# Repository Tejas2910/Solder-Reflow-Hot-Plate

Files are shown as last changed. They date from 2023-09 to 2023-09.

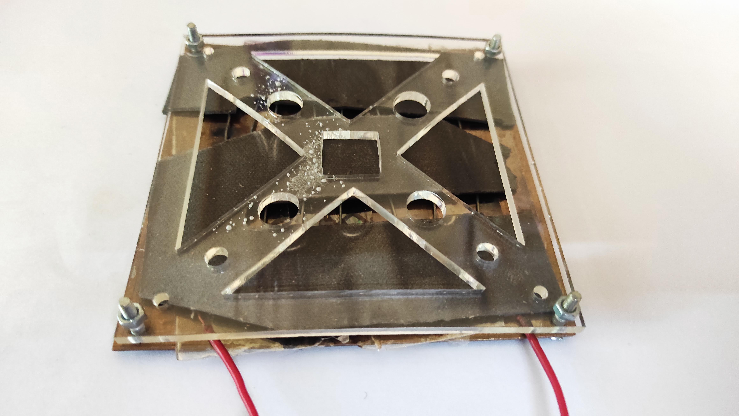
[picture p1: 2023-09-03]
Assembly.jpg

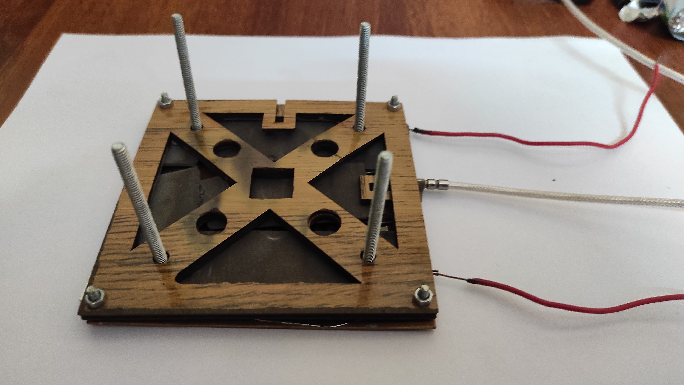
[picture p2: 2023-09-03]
Assembly_Final.jpg

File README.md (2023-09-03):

# Solder-Reflow-Hot-Plate
## Course Project EE344: Electronic Design Lab

Project Details:
 -  Recipient of Best Project Award in the Electrical Engineering Department among 200+ students for creating Solder Reflow Hot Plate instrument to solder SMD components 
 -  Engineered a high-performance heating element reaching temperatures up to 300°C, a cooling mechanism capable
    of dropping temperatures at a maximum rate of 3°C/s, and a precision feedback circuit for temperature control
 -  Collaborated within a 3-member team to design an intuitive web interface for configuring reflow profiles, a user-
    friendly TFT LCD display for real-time information, a 3D-printed enclosure and PCB layouts using Eagle

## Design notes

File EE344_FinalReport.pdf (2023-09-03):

EE344: Electronic Design Lab | Final Project Report

# EE344: Electronics Design Lab

# Final Project Report

# Reflow Oven for Soldering SMD Components

# TUE- 11

Akshata Koshti | 200070034
Darshan Sinnarkar | 20D070079
Tejas Amritkar | 20D070081

### 1. Project Title:

Reflow Oven for Soldering SMD Components

### 2. Group Number: TUES-11

### 3. Team members:

Akshata Koshti 200070034
Darshan Sinnarkar 20D070079 Tejas Amritkar 20D070081
4. Circuit Schematic and Layout: Circuit_Schematic_Layout (https://drive.google.com/drive/folders/1hkzOSJ5yrxFGMIBhelCKWo8H-GT9ofpd?usp=sharing) Also added at the end of the document.

### 5. Project abstract:

Soldering SMD components requires practice, it is time consuming
and the quality of soldering depends on the skill.
Aim of this project is to build a reflow oven which follows a configurable reflow profile accurately and covers a large temperature range. We aim to build the system using Nichrome coil mounted on an Copper plate as heating element, a web-interface to add/configure reflow profile, a simple user interface including screen and buttons and an elegant 3D printed PLA enclosure. Proposed system can also be used for de-soldering SMD components.

### 6. Project Goal:

Goal of the project is build a reflow oven with heating plate size as 100mm x 100mm which covers a large temperature range (up to 300 oC). Reflow oven should have an option to change reflow profile according the solder paste used. The heating plate should be able to drop temperature after reflow profile peak quickly (about 3oC/second). The heating of surface should be approximately even. Reflow oven should have a screen where relevant data (like current temperature) is displayed and a few buttons to control the oven. Entire project is to be enclosed in a suitable enclosure.

### 7. Components:

a. Copper plate:
Copper Plate of dimensions 100x100x2mm is used as heating surface. Copper is chosen because of high conductivity, it is easily available, requires less energy to heat up than aluminium (for same dimensions), dissipates relatively less energy compared to aluminium.

b. Nichrome Coil:
Nichrome wire will be used as a heating element. Resistance of nichrome wire almost remains constant with temperature. Therefore, steady state temperature is entirely dependent on current through the wire.
T directly proportional to I^2 RMS or V^2 RMS.
Ref - http://www.brysonics.com/heating-a-nichrome-wire-with-math/
c. Pt100 temperature sensor:
IT can measure temperature from -200 to 420-

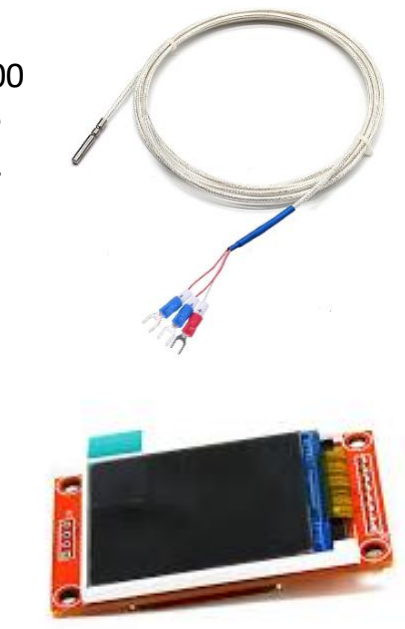
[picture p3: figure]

degree C. At 0°C, the sensor has a resistance of 100
Ohm and resistance increases as the temperature increases. The sensor has a response time of 1ms. The sensor has an accuracy of around 0.385 Ohm/°C.
d. TFT screen
We will use the 1.8 inch TFT LCD to display the current temperature, time and other important parameters on the screen. 1.8 Inch TFT LCD Module display uses 4-wire SPI to communicate and has its own pixel-addressable frame buffer, it can be used with every kind of microcontroller. We can use it with 3.3V(in our case) or 5V power and logic.

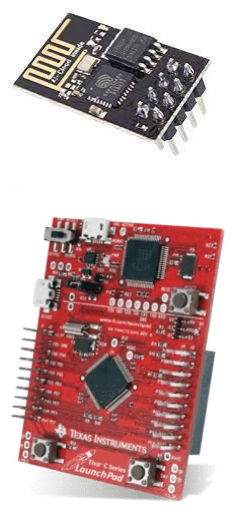
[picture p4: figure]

e. ESP01
The ESP01 is a small, low-cost, and easy-to-use microcontroller board that includes built-in WiFi connectivity. We will be using this microcontroller to host a website and control the reflow oven remotely.
f. TM4C123GH6PM TIva C board

We will be using TM4C123GH6PM Tiva C board as a microcontroller. The board includes a range of peripherals, including UART, I2C, SPI, PWM, 12-bit ADC. The board meets all the feature needed for the
project. It | will be coded with C programming
language.

g. Cooling Fan:
We will be using an 8025 5V cooling fan for cooling mechanism of reflow oven. We are using 80 x 80 x 25 mm casing Frame size of fan which fit comfortably inside the oven.

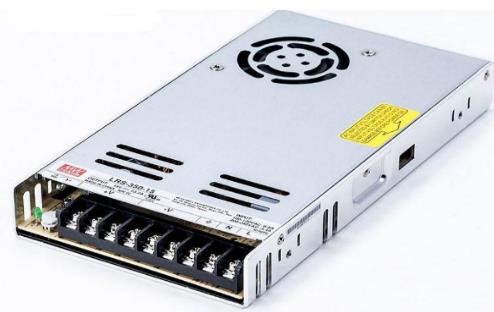
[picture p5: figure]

h. Power supply
We have used SMPS, 12V 10A for supplying power. It provides enough current current to drive our circuit.
i. LM2596
We wil be using LM7805 linear voltage regulator to convert 12 V (from 12 V
adapter) | to 5V DC.
j. Push Button:

We will be using push button to near LCD mounted on the casing. We will use 4 push button to these 4 features: mode select, resume, pause and reset.

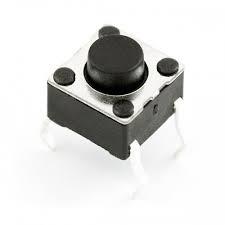
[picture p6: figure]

k. Mica sheet
Mica sheet was easily available and suitable for insulating the copper plate and nichrome coil.
l. Relay
Instead of using IRF3205 power mosfet and 2N2222 for controlling the nichrome coil, relay and related circuits are used which include BC547 NPN BJT and diode 1n4001 (both available in WEL). The circuit diagram is attached. A similar circuit is used for controlling cooling fan.

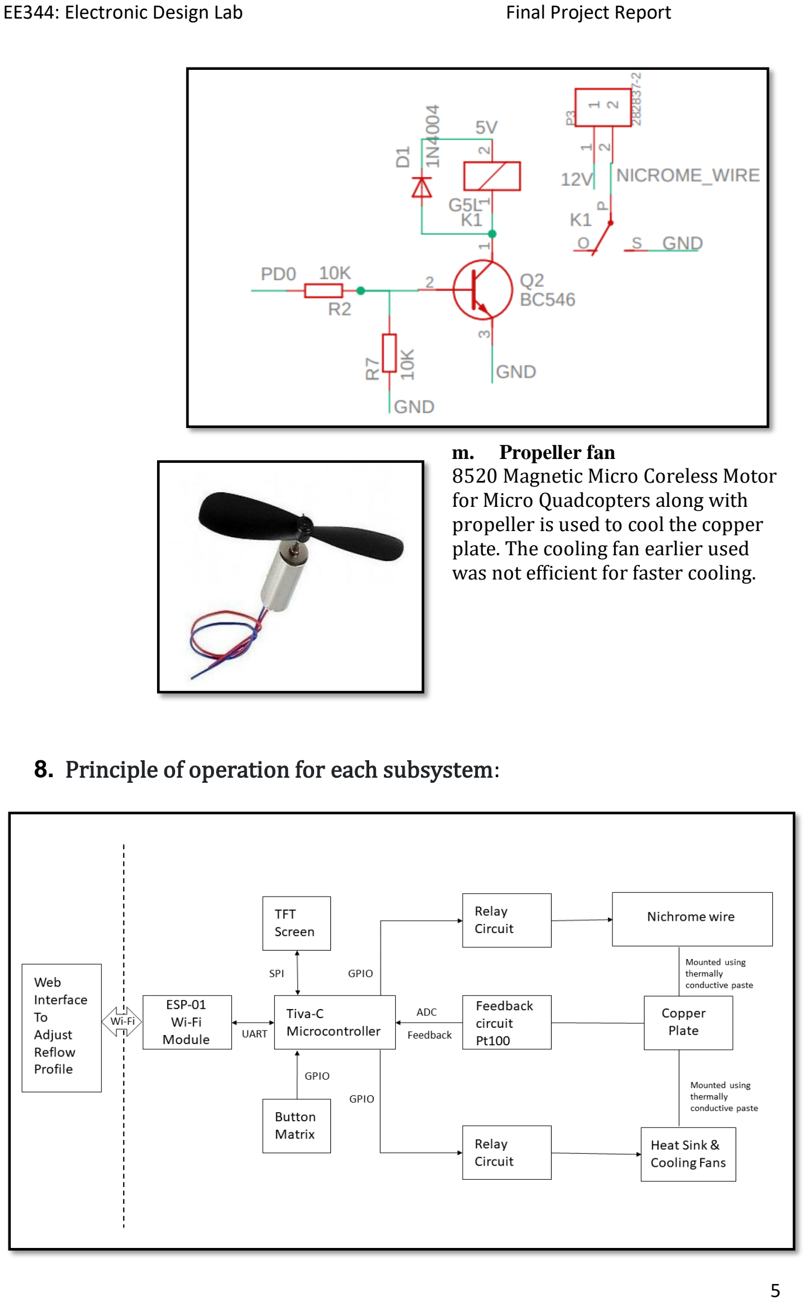
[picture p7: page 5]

m. Propeller fan
8520 Magnetic Micro Coreless Motor for Micro Quadcopters along with propeller is used to cool the copper plate. The cooling fan earlier used was not efficient for faster cooling.

### 8. Principle of operation for each subsystem:

Project consists of following sub-systems:
a. Heating Circuit
b. Cooling Circuit
c. Feedback Circuit
d. Web interface
e. User Interface
a. Heating Circuit:
- Copper Plate of dimensions 100x100x2mm is used as heating surface.
- Nichrome wire will be used as heating element to heat up to desired temperature. It will be power up by the 12 V DC supply.
- Relay circuit is to be used to control power to Nichrome wire using GPIO of microcontroller.
b. Cooling Circuit:
Air Cooling: In order to have an efficient cooling effect 8520 motor is used as cooling fan to transfer heat out of enclosure.
c. Feedback Circuit:
Pt100 temperature sensor along with voltage divider circuit is used as feedback.
d. Web-interface:
We aim to build a web-interface for configuration of reflow profile and to update collected data to user desktop/laptop. To achieve this ESP01 Micro -controller is used.
e. User Interface:
- 1.8’ ST7735 TFT Screen: Screen communicates to Micro-controller using SPI communication and provides user with useful data.
- Button Matrix: Used to take inputs from user to select reflow profile, start/stop process, and other basic utilities.

### 9. Method - Heating element setup:

Copper plate is being used as heating surface. For heating element 22 AWG Nichrome wire (not insulated) is used. There is need to add an electrically insulating layer between copper plate and nichrome wire. For electrical insulation Mica sheet is used between Nichrome wire and copper plate.

For maximum efficiency, full length of Nichrome wire needs to be in strong contact with Mica sheets. Hence entire assembly is as follows:
a. Copper Plate
b. Mica Sheet
c. Nichrome Wire
d. Asbestos sheet for thermal insulation/buffer
e. Two Wooden plates

In absence of Asbestos sheet wooden plate is burnt by heat from
nichrome wire which leads to smoke and burning smell.
A small slit is made in top wooden sheet to hold PT100(Temperature Sensor) in contact with copper plate.
Four Screw-nuts hold the entire assembly together.

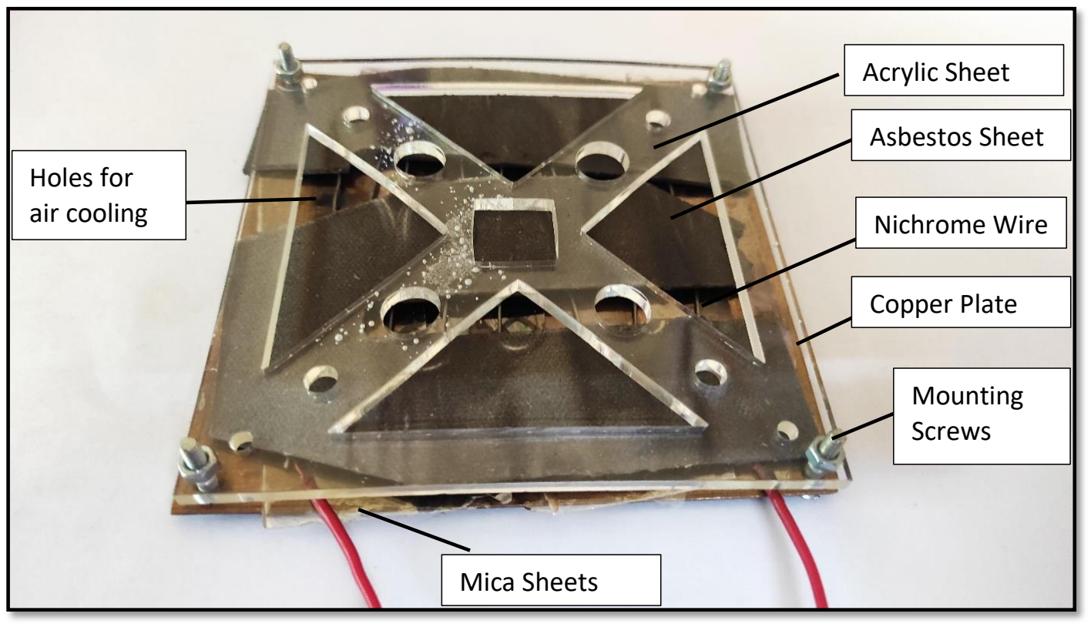
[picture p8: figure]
Acrylic Sheet; Asbestos Sheet; Nichrome Wire; Copper Plate; Mounting Screws; Mica Sheets; Holes for air cooling

First Version of assembly. All layers as described can be clearly seen.

3mm Acrylic sheet was earlier used as last layer, considering temperature on other side of asbestos sheet does not exceed above 150oC, which is below melting point of acrylic(160oC). However, at much lower temperatures Acrylic sheet begins to lose structural integrity and starts deforming.

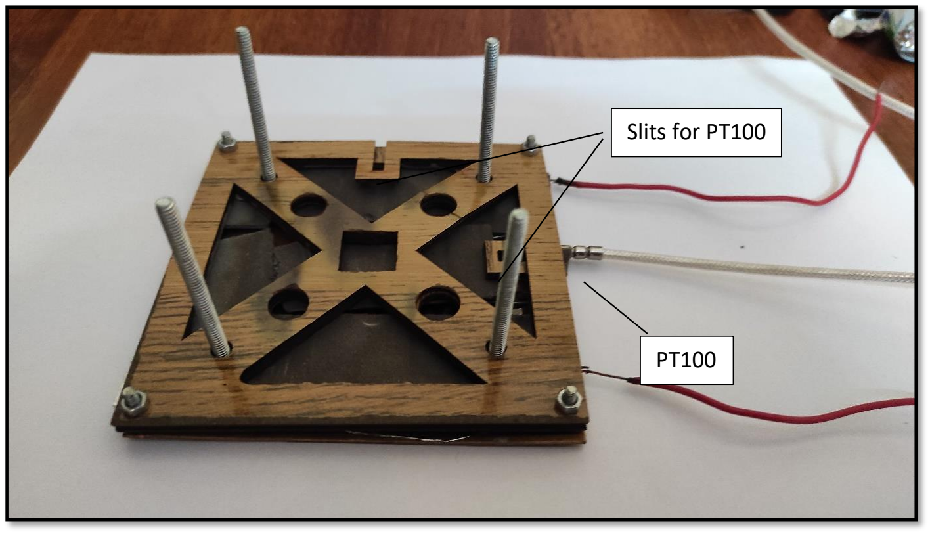
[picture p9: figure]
Slits for PT100

Final Assembly with wooden plates

Long Screws are used to attach this heating subsystem to 3D printed PLA enclosure. These also create a temperature gradient such that PLA does not melt where screws are attached.

Technical Specifications of parts:

1mm thick Copper Plate – 105x105 mm. 22 AWG Nichrome wire with 3Ω resistance. 2mm Asbestos sheet.
Two 2mm 105x105mm wood sheets.
5mm Screws to create temperature gradient.

### 10. Method - ESP-01 Wi-Fi Module Setup:

Wi-Fi Module procured from WEL is ESP-01 module with ESP8266EX micro-controller. It comes with pre-loaded firmware which accepts AT commands through UART.

To create wireless interface to add custom reflow profiles and load in Tiva-C micro-controller.
To achieve this, create a web-server on ESP-01 and host a local website through which user can set custom user profile.

To use this module, it can be interfaced with Tiva-C using UART and AT commands can be used to interact with Wi-Fi module. However, this is inefficient architecture as it creates additional load on Tiva-C micro-controller, takes up storage space of Tiva-C and large amount of data is transferred over UART.

Instead, we can use ESP-01 on-board flash to store program and use computing capabilities of ESP8266EX MCU to share computing load on Tiva-C.

Steps:

1. Download and set-up ESP8266 RTOS SDK with Msys32 from Espressif website. (Documentation) (https://docs.espressif.com/projects/esp8266-rtos-sdk/en/latest/get-started/)
2. Run mingw32.exe and run these commands before every use. PATH="${HOME}/xtensa-lx106-elf/bin:${PATH}"
export IDF_PATH=~/esp/ESP8266_RTOS_SDK
3. Use template code from
(SDK_PATH)/examples/protocols/http_server/simple
and modify it according to needs.
4. Create suitable webpage HTML and JavaScript files and add them as EMBED files. For this, save html and JavaScript files in main directory and add following lines in CMakeLists.txt and component.mk.

CMakeLists.txt =>

component.mk =>

5. Referring to example provided create suitable URI and use HTTP GET to get data from browser.
6. Use a USB-UART converter and use the following schematic.

PATH="${HOME}/xtensa-lx106-elf/bin:${PATH}" export IDF_PATH=~/esp/ESP8266_RTOS_SDK

register_component(EMBED_FILES upoad_script.html")

COMPONENT_EMBED_FILES += upload_script.html

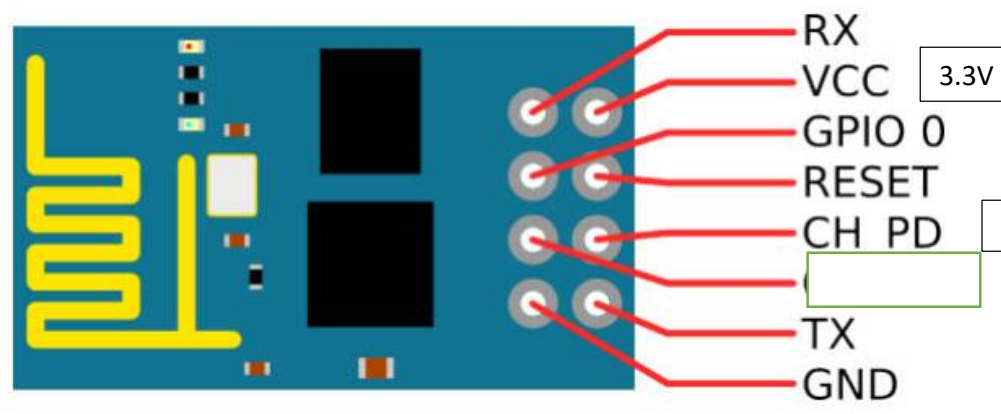
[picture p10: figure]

7. Use menuconfig to set upload port as mentioned in documentation in Step 1 and flash custom firmware.
8. While flashing connect GND to GPIO 0 to put the module in boot mode. Later connect RESET pin to GND for a second and release to activate the normal configuration.
9. Connect the ESP-01 module to Tiva-C through UART and read data as collected through web-interface.

Before executing Step 6, check the flash usage. We have upgraded the default flash of 1 MB in ESP-01 to 4 MB.

3.3V

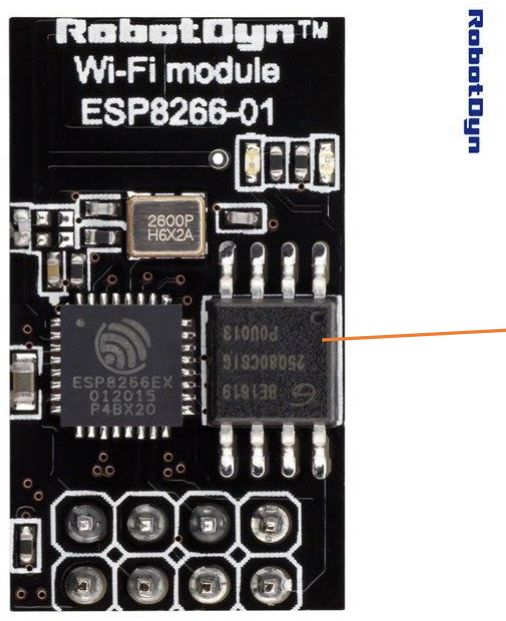
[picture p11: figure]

Upgrade this flash to 4 MB to store html and JavaScript
files.
(Plotly JavaScript Library as described later can also be stored in the flash)

### 11. Method - Feedback circuit:

Pt100 RTD temperature sensor is used to take temperature reading of the hot copper plate. Pt100 changes its resistance values nearly in linear proportion with the temperature. Temperature reading is used to switch on/off relay circuit which further switched on/off current going through nichrome coil and fan.

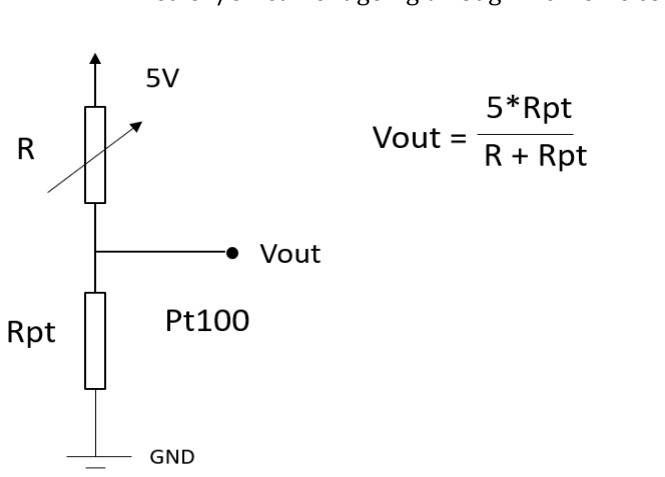
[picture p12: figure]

Pt100 temperature sensor is put in a voltage divider circuit with another resistor Rs as shown in the figure. We have used potentiometer in instead of constant Rs, with a value of 120 Ohm. Output of this circuit (Vout) is an input to Micro-controller through an in-built 12-bit Analog-to-Digital converter (ADC). Resistance of the Pt100 is calculated from the Vout with the formula shown in figure. We found that temperature of the Pt100 varies linearly with its resistance value as shown:

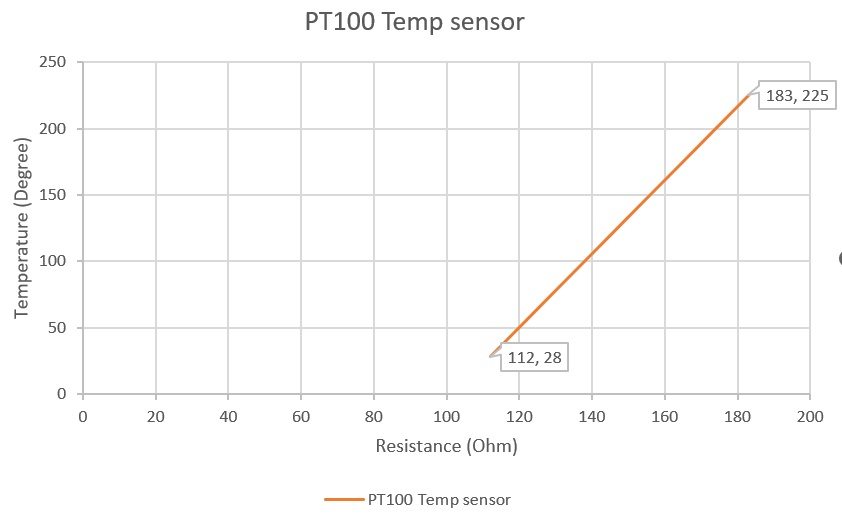
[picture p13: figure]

(Note: Feedback circuit in the prototype is not on PCB because the routes had lot of noise as it was incorrectly placed near 6A routes.)

### 12. Method - Cooling Circuit:

8520 Magnetic Micro Coreless Motor for Micro Quadcopters along with propeller is used as a cooling mechanism. Both nichrome coil and fan is controlled with relay circuit. If the temperature is below 220 degree C, we keep the fan switched off and nichrome coil is switched on. If the temperature is between 220-2330 degree C, we start the cooling fan with nichrome coil switched on. If the temperature is above 2330 degree C, fan is switched on and nichrome coil is switched off.

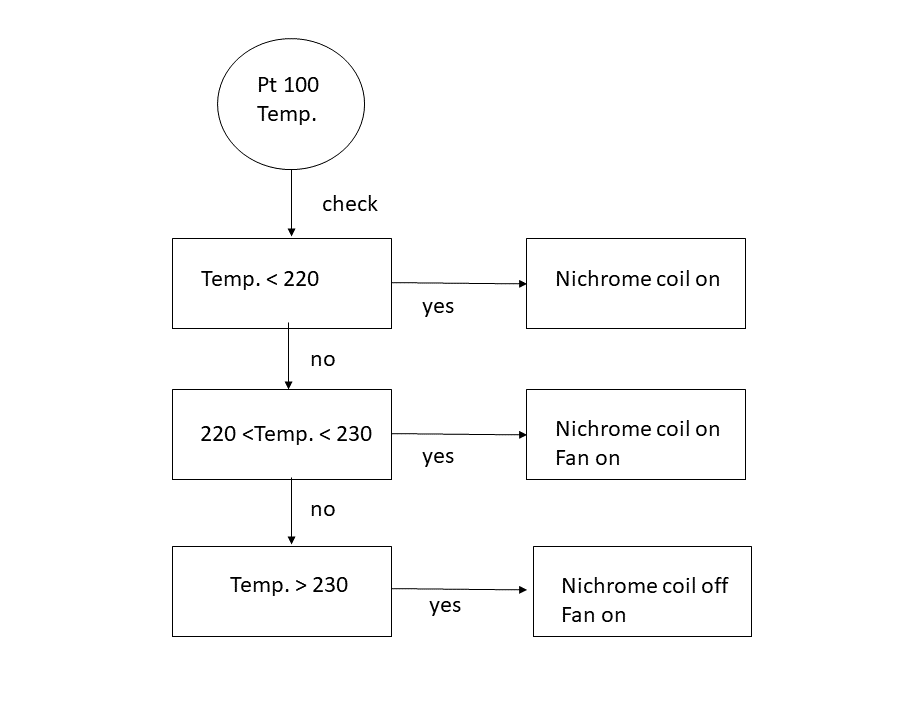
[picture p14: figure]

### 13. Method - User Interface

1.8’ ST7735 TFT Screen is used to show useful data such as current temperature, time elapsed, resistance value of pt100, current status of nichrome coil, percentage of completion of reflow process. TFT screen communicates to micro-controller using SPI communication.

Test setup and method:

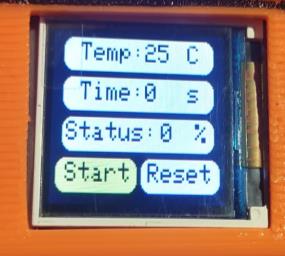
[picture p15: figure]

1. TFT screen is interfaced using SPI communication as shown.
- MOSI(Master Output Slave Input): (PIN SDA) Used by Tiva C to send the data TFT screen.
- SCK(Serial Clock): (PIN SCK) Used to synchronous the transfer of data between the Tiva C and screen. The clock is generated by the Tiva C.
- SS(Slave select): (PIN CS) Used to select the slave device with which Tiva C wants to communicate.
- RESET: Used to reset the TFT screen.
- LED: This is the backlight pin, which is used to control the brightness of the screen backlight.
- A0(D/C): This is the data/command pin, which is used to differentiate between data and command signals.

14.Method - Integrated Setup:

In this part, we integrated all subsystems.

Tiva-C MCU was programmed accordingly and it was controlling the temperature of Copper plate while displaying technical details on screen.

a. Heating element:

Connected using relay circuit as mentioned. Circuit was designed using NPN transistor (BC547), diode(1N4001) and a (5V, 5 pin) relay.

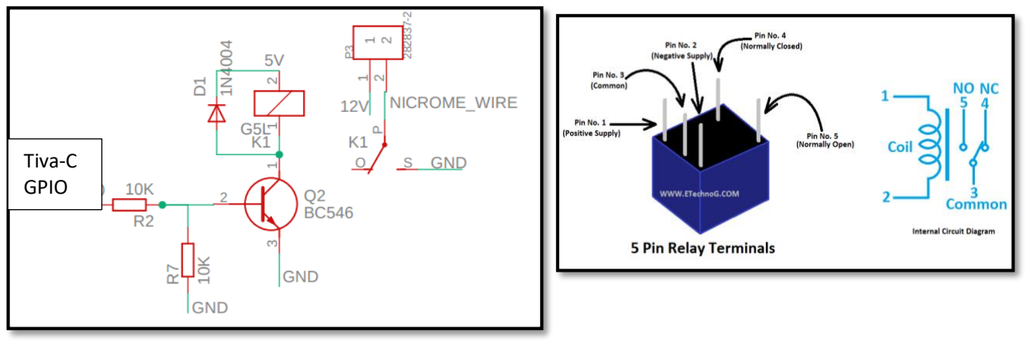
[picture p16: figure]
Tiva-C GPIO

b. Feedback Circuit:

In the assembly of heating element Pt100 was placed which acted as feedback to micro-controller through a resistor voltage divider circuit.
A potentiometer was connected in series with PT100 to have control over the sensitivity of the voltage. Default value of potentiometer =120 Ω.
(Rest structure and figures are not specified as it is same as described in respective experiment section.)
c. User Interface:
Display was used to show relevant data on screen.
(Rest structure and figures are not specified as it is same as described in respective experiment section.)

d. ESP-01 Wi-Fi Module:

Wi-Fi Module was set up as described earlier.
It is connected using UART to Tiva-C. ESP-01 sends corner points of reflow curve. Arrays are generated in Tiva-C after data is received from ESP-01. Currently ESP-01 connects to Wi-Fi with SSID: hhhhh, password: mypassword. Fing application(Android) can be used to find the local IP address where the webpage is hosted.
e. Cooling Circuit:

Small drone propeller motor was mounted below Heating element and controlled in similar way as nichrome coil.

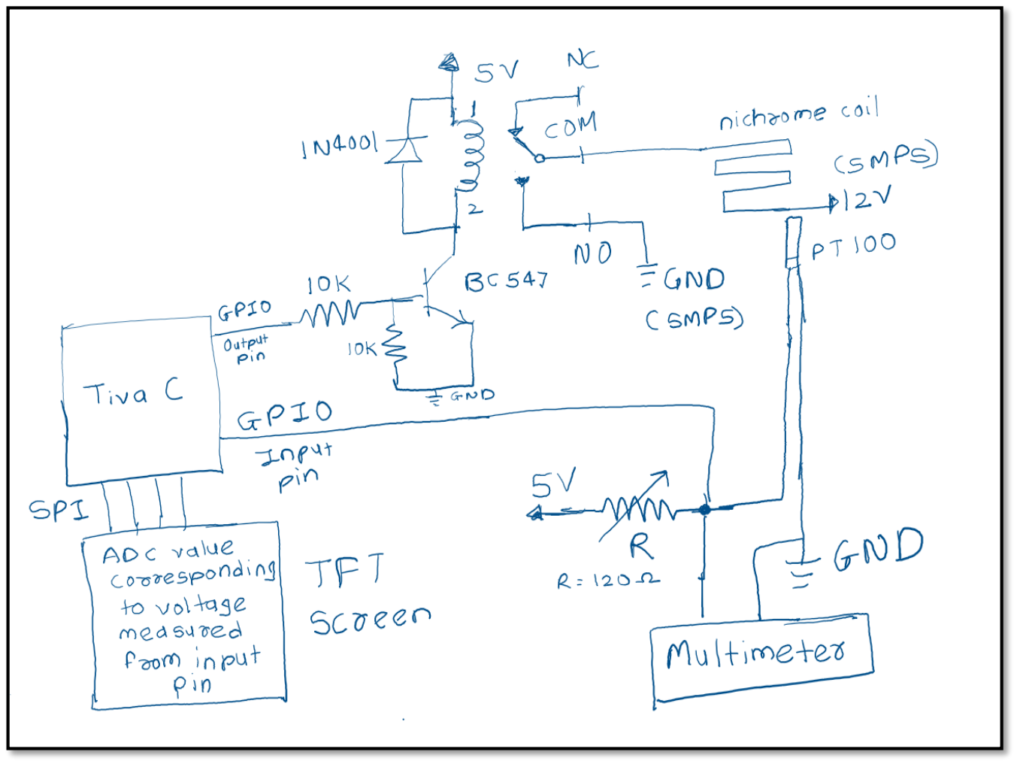
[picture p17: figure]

Integrated test setup figure

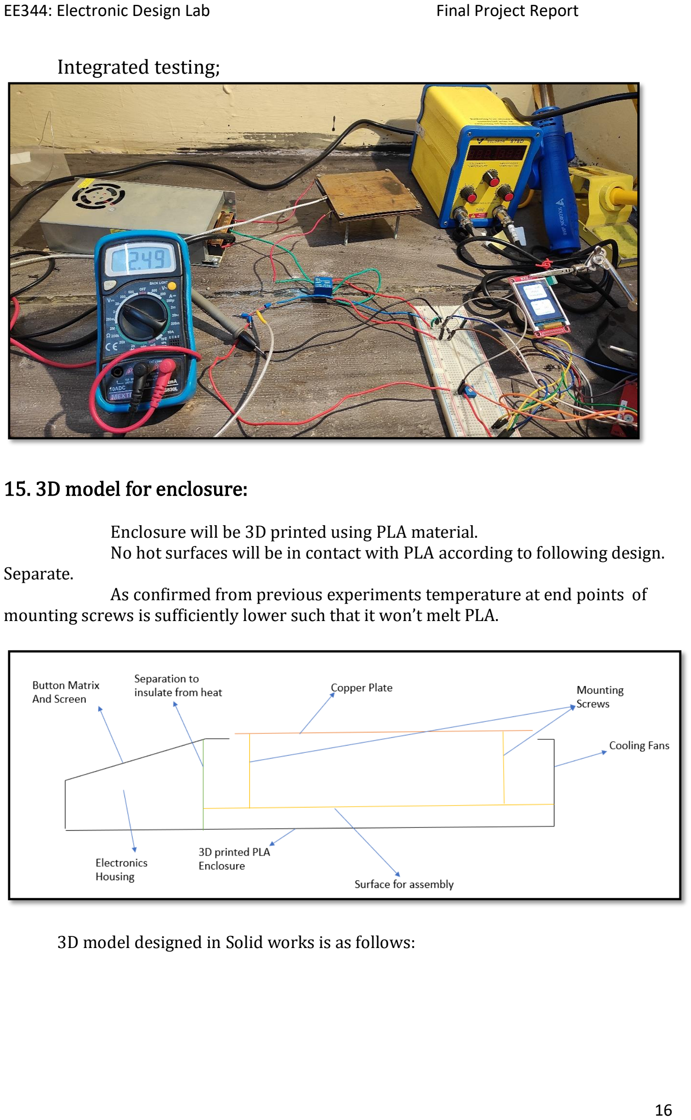
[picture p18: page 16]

Integrated testing;

15. 3D model for enclosure:

Enclosure will be 3D printed using PLA material.
No hot surfaces will be in contact with PLA according to following design. Separate.
As confirmed from previous experiments temperature at end points of mounting screws is sufficiently lower such that it won’t melt PLA.

3D model designed in Solid works is as follows:

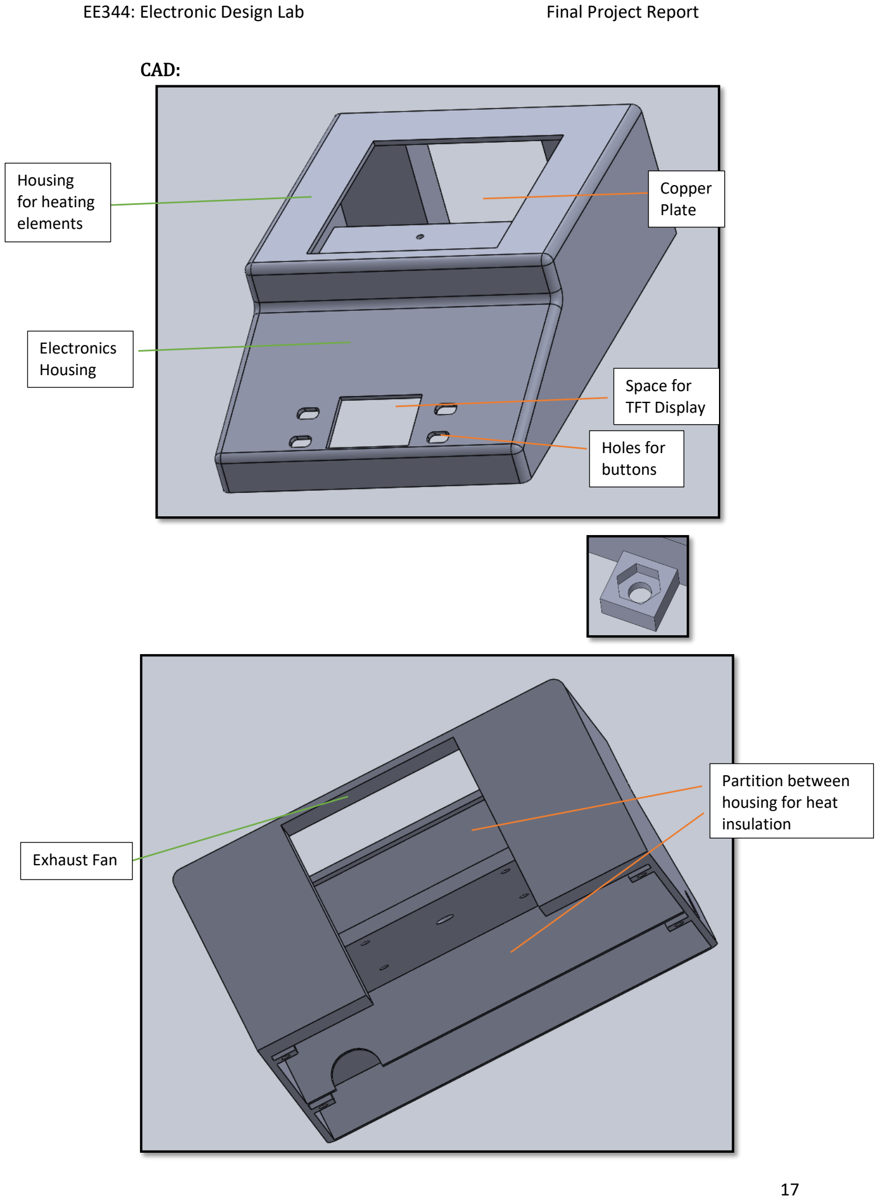
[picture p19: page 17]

CAD:

Holes for
buttons

Space for
TFT Display

Electronics
Housing

Housing
for heating
elements

Copper
Plate

Partition between
housing for heat
insulation

Exhaust Fan

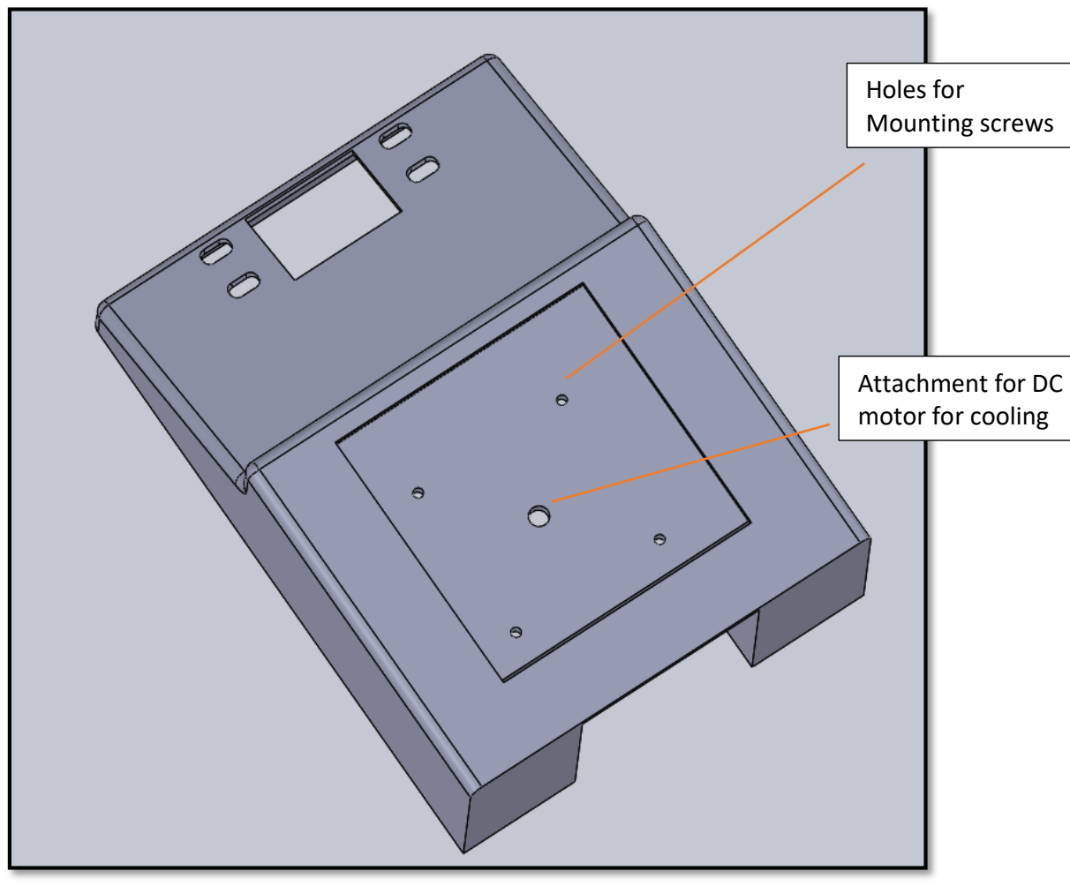
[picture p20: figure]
Holes for Mounting screws; Attachment for DC motor for cooling

16. Result and Observation
Final Prototype:

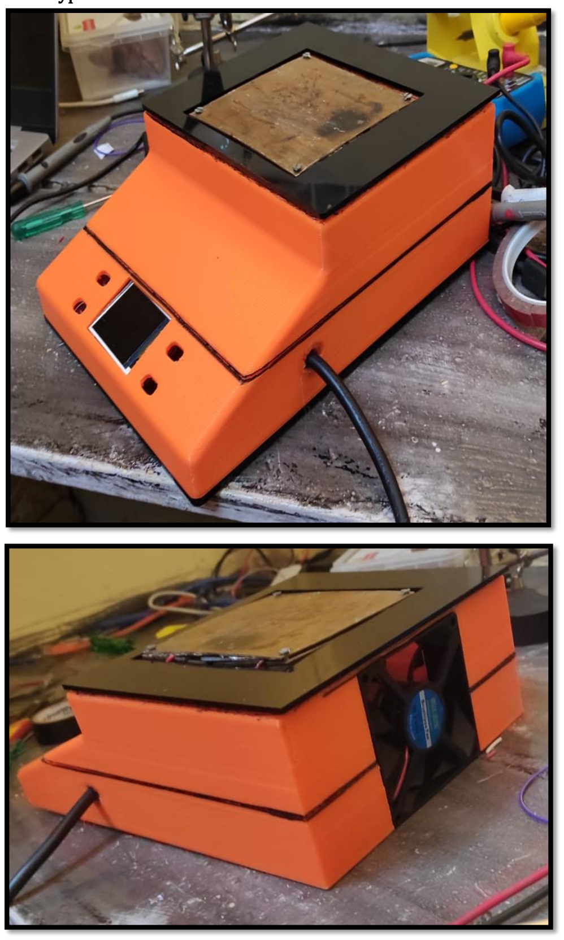
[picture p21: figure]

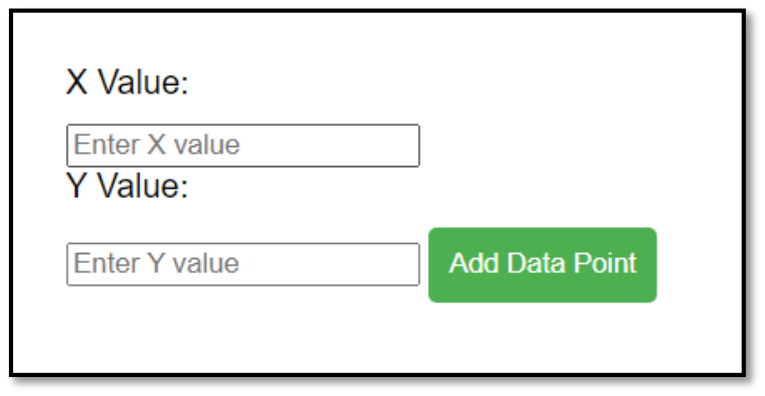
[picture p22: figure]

Webpage we created:

In the “/preview” URI, user can add multiple points using similar form and the webpage uses linear interpolation to fill in the rest data points. Example, if (0,0) and (5,5) is given using html form, the preview will be shown as [(0,0), (1,1), (2,2), (3,3), (4,4), (5,5)].

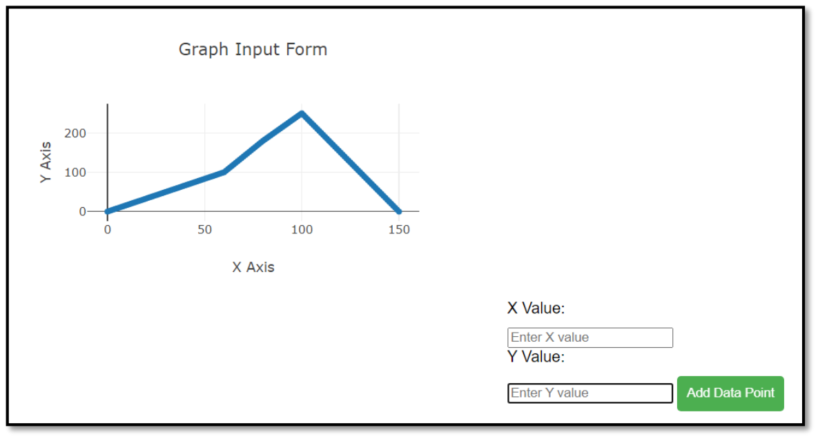
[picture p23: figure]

Example of reflow profile generated using “/preview” URI

As included in figures, webpage generates required reflow profile and it can be obtained in ESP-01 as array.

This is a simple webpage created by us to get data from browser. URI for the specific webpage is “/get_data”.

X represents time in seconds and Y represents Temperature at that time according to reflow profile.

Integrated circuit testing:

The pin output was high(nichrome coil on) till the ADC value 3500 which corresponds to 2.84V in multimeter(across pt100) where soldering wire melts on the copper plate. The output was triggered to low when the feedback sensor (temperature sensor) output reaches 3500 i.e., 2.84V.

The feedback input was also displayed on the TFT screen. The value ptvolt is relevant for the testing it shows the ADC value of the voltage across Pt100.

The voltage drop across the Pt100 was stuck at 1.1V when relay transitions to on due to the inductive nature of relay coil. (Somehow it was affecting other circuits.) We added a 10μF capacitor in parallel with the relay coil to provide sudden current requirement.

We obtained the following reflow profile of temperature from two experiments:
1. With cooling mechanism (Fan is switched on, after temperature of the copper plate reaches desired value.
2. Without cooling mechanism (Fan is switched off for the entire time of experiment)

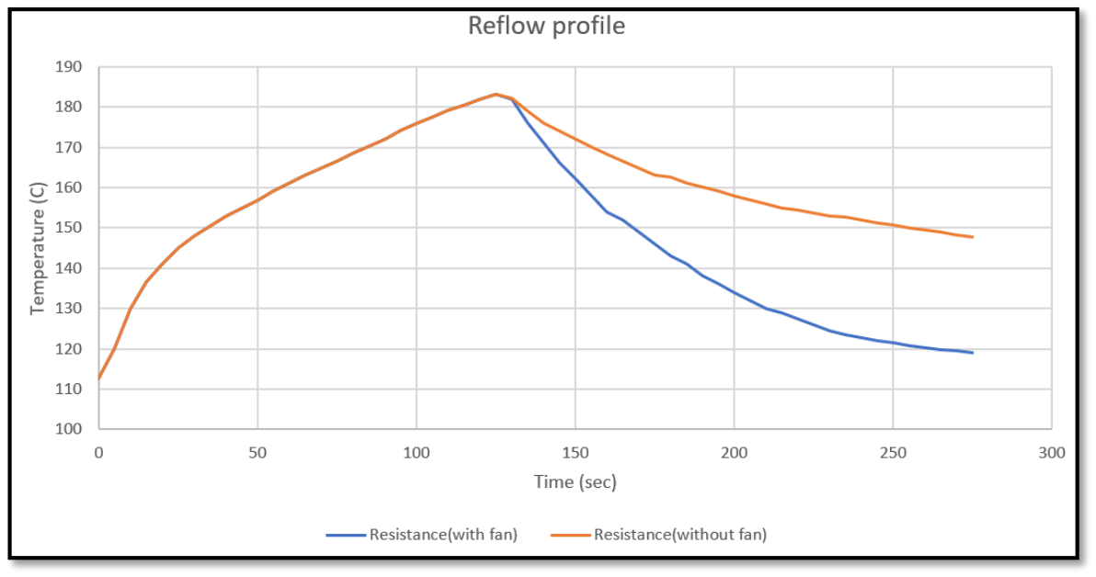
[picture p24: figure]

With the voltage divider circuit, we are able to control the temperature of the copper plate. Pt100 has sufficient precision to control the temperature required in this project.

With the above above-mentioned assembly connected to 15V voltage source (SMPS). PT100 is used to measure copper plate temperature.
a. Current Drawn = 4.8 A
b. Time Taken for temperature to rise 250oC = 130 seconds
c. For temperatures above 280oC, wooden sheet starts burning as asbestos sheet is unable to create enough temperature gradient.

d. Long Screws create sufficient temperature gradient such that other end can be mounted on PLA enclosure.

Heating element successfully reaches sufficient temperatures fast enough to follow standard reflow profile and melts Solder wire.

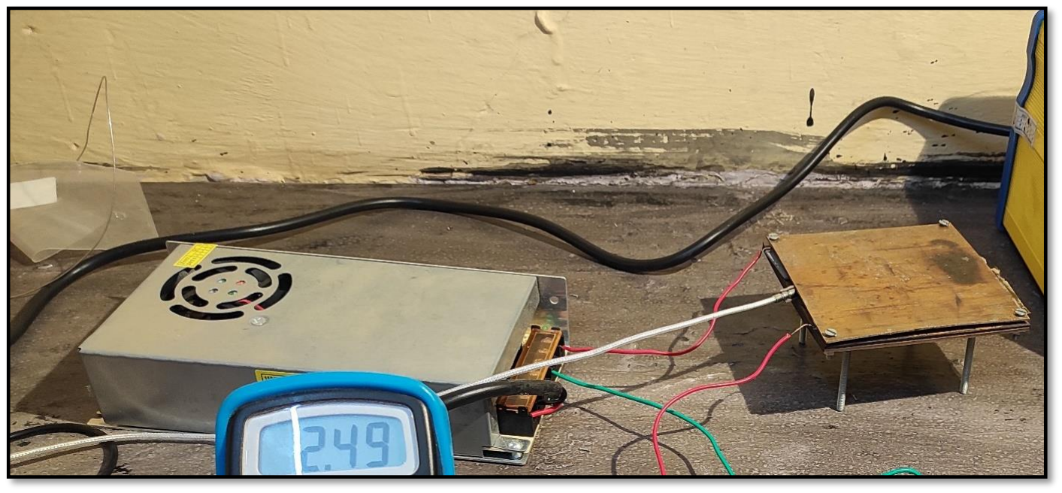
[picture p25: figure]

PCB that we designed:

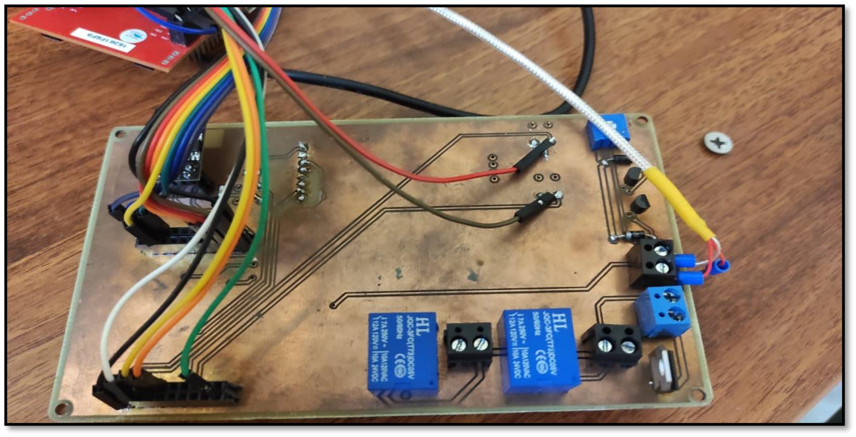
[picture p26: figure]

17. Conclusion:
10cm X 10cm Soldering hot plate was built. We demonstrated soldering and de-soldering of component on ESP01 board. We have successfully developed local web-interface using ESP-01 Wi-Fi module. All the components were housed in an enclosure. All objectives mentioned in the problem statement were completed.

18. Future work:
1. User Interface:
Screen-touch TFT screen can be used, which will make our model more interactive. Push-buttons can be avoided with touch-screen.
2. Heating Element:
Area where nichrome wire is connected to copper wire gets oxidized after 10 cycles. Thicker copper wires need to used.
Wooden sheets can be replaced with CNC machined steel plates with proper electrical insulation which will eliminate the wood burning and smoke problem.
3. Web interface:
Style of web-page can be improved.
Note: Current code uses Plotly CDN from this link (https://cdn.plot.ly/plotly-latest.min.js) for plotting graph. A lite version of this CDN can be implemented so that no Internet connection is required to run the Web Interface. After this ESP-01 Wi-Fi mode can be changed from Station (STA) to Access Point (AP).
4. PCB:
Some of the PCB routes are not connected. Communication between ESP01 and Tiva C is not working because of that. At some points top and bottom layers of the PCB are not connected, eg. Connectors. So, we have used jumper wires at these points. PCB cab be manufactured from industrial PCB manufacturer to make PCB more robust.
5. Controlling over WiFi:
Using the web interface through ESP01, TIva C will get an array of the format [time: temperature].
[time: temperature] - time is in seconds and temperature in C.
This part has several bugs, which we could not resolve within given time frame.
19. Link to demo videos:

All the essential files/videos are in this folder: https://drive.google.com/drive/folders/1hkzOSJ5yrxFGMIBhelCKWo8H-GT9ofpd?usp=sharing (https://drive.google.com/drive/folders/1hkzOSJ5yrxFGMIBhelCKWo8H-GT9ofpd?usp=sharing)

20. Bill of Material or BOM:
Index | Component | Price
1 | SMPS 12V 10A | Rs. 885
2 | Buck Convertor | Rs. 70
3 | ESP01 | Rs. 120
4 | Tiva C | Rs. 4700
5 | ST7735 1.8-inch screen | Rs. 600
6 | BC547 (x2) | Rs. 4
7 | 1N4007 Diode (x2) | Rs. 4
8 | Relay (220V 10A/5V DC) (x2) | Rs 40
9 | PT100 Temperature sensor | Rs. 140
10 | Nichrome wire 22 AWG | Rs. 20
11 | Copper plate | Rs. 360
12 | Cooling fan | Rs. 66
13 | Mica sheet | Rs. 35
14 | Asbestos sheet | Rs. 35
15 | Wooden sheet | Rs. 50
16 | Screw terminal block connector (x4) | Rs. 60
17 | Push button (x4) | Rs. 40
18 | Small drone motor with propellor | Rs. 100
19 | Mounting Screws | Rs. 50
20 | PLA filament | Rs. 100
21 | Resistors, capacitors | Rs. 50

22 | Jumper Wires | Rs. 50
23 | Potentiometer | Rs. 10
| Total | ~ Rs. 7600

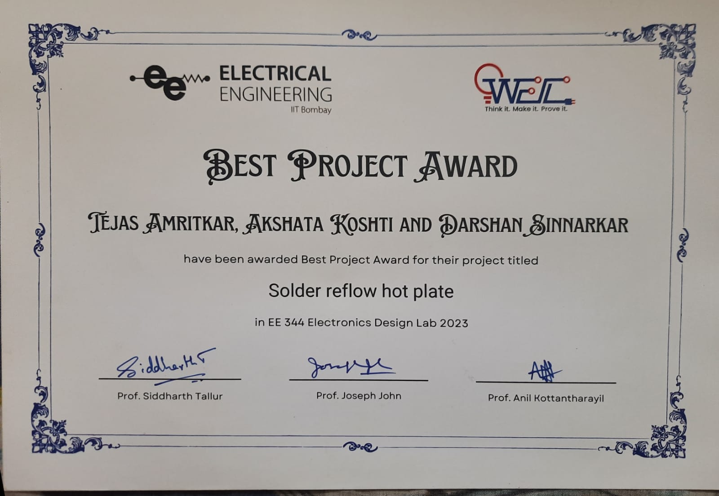
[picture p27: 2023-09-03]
Best Project Award.jpeg

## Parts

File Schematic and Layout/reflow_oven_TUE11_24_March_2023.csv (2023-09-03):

Qty | Value | Device | Package | Parts | Description | AVAILABILITY | COMMENT | DESCRIPTION | HEIGHT | MANUFACTURER_NAME | MANUFACTURER_PART_NUMBER | MF | MOUSER_PART_NUMBER | MOUSER_PRICE-STOCK | MP | MPN | OC_FARNELL | OC_NEWARK | PACKAGE | POPULARITY | PRICE | PROD_ID | PURCHASE-URL | SF_SKU | VALUE
4 |  | TAC_SWITCHPTH | TACTILE-PTH | S3, S5, S6, S7 | Momentary Switch
4 | 0.1u | C-USC1206 | C1206 | C1, C2, C3, C5 | CAPACITOR, American symbol
1 | 1.8_TFT" | 1.8_TFT" | 1.8_TFT" | U$1
4 | 10K | R-EU_R1206 | R1206 | R2, R7, R8, R9 | RESISTOR, European symbol
2 | 1N4004 | 1N4004 | DO41-10 | D1, D3 | DIODE
4 | 1k | R-EU_R1206 | R1206 | R1, R4, R5, R6 | RESISTOR, European symbol
4 | 282837-2 | 282837-2 | TE_282837-2 | P1, P2, P3, P4 | TERM BLOCK 5.08MM 2POS SIDE ENTY Check availability | In Stock | 282837-2 | Connector Terminal Blocks Receptacle 2 Position 5.08mm Solder Straight Thru-Hole 13.5A/Contact |  |  |  | TE Connectivity |  |  | 282837-2 |  |  |  | None |  | None |  | https://pricing.snapeda.com/search/part/282837-2/?ref=eda
1 | 5k | TRIMPOT-PTH-10MM-KNOB-1/2W-10% | TRIMPOT-PTH-3386U | VR1 | Trimming Potentiometer (Trimpot) |  |  |  |  |  |  |  |  |  |  |  |  |  |  |  |  | RES-09730 |  | COM-09806 | 10k
1 | 7805 | 7805 | 78XXS | IC1
2 | BC546 | BC546 | BC546 | Q1, Q2 | TRANSISTOR, NPN, TO-92 |  |  | TRANSISTOR, NPN, TO-92 | 5.33mm | onsemi | BC546 |  | 512-BC546 | https://www.mouser.co.uk/ProductDetail/onsemi-Fairchild/BC546?qs=UMEuL5FsraDWGn9zuahUkw%3D%3D
1 | EK-TM4C123GXL | EK-TM4C123GXL | MODULE_EK-TM4C123GXL | U2 | ARM® Cortex®-M4F Based MCU TM4C123G LaunchPad™ Evaluation Kit Check availability | In Stock |  | ARM® Cortex®-M4F Based MCU TM4C123G LaunchPad™ Evaluation Kit |  |  |  | Texas Instruments |  |  | EK-TM4C123GXL |  |  |  | None |  | None |  | https://pricing.snapeda.com/search/part/EK-TM4C123GXL/?ref=eda
1 | ESP8266-01/ESP-01 | ESP8266-01/ESP-01 | XCVR_ESP8266-01/ESP-01 | U1 | MakerFocus 4pcs ESP8266 ESP-01 Serial Wireless WiFi Transceiver Receiver Module 1MB SPI Flash DC3.0-3.6V Internet of Things WiFi Module Board Compatible with Ar duino Check availability | Not in stock |  | MakerFocus 4pcs ESP8266 ESP-01 Serial Wireless WiFi Transceiver Receiver Module 1MB SPI Flash DC3.0-3.6V Internet of Things WiFi Module Board Compatible with Ar duino |  |  |  | AI-Thinker |  |  | ESP8266-01/ESP-01 |  |  |  | Non-Standard AI-Thinker |  | None
2 | G5L | G5L | G5LE | K1, K3 | RELAY |  |  |  |  |  |  |  |  |  |  |  | unknown | unknown |  | 10

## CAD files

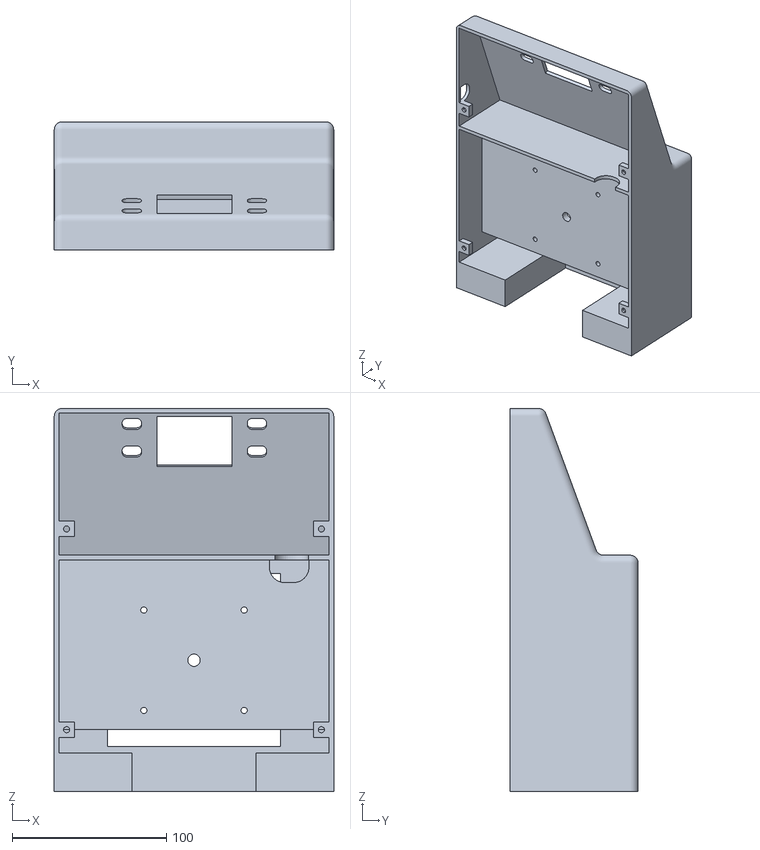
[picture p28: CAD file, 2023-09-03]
Solidoworks models/MainEncl.STL
181.0 x 83.0 x 248.0

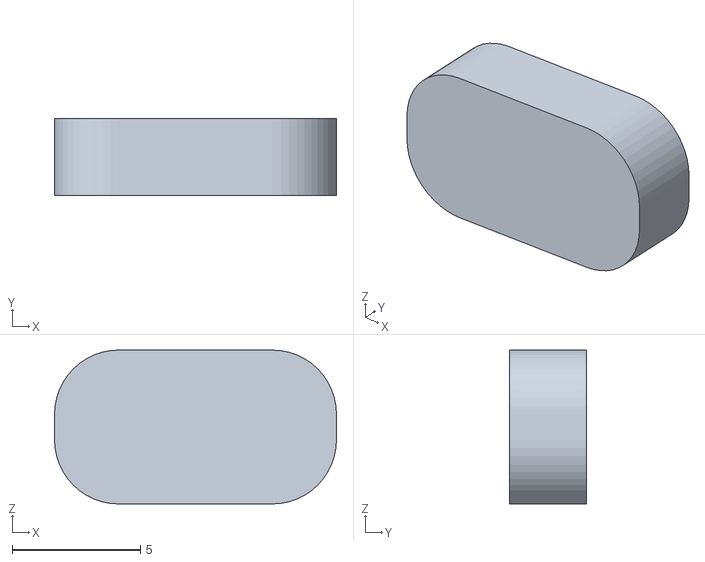
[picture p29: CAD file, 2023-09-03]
Solidoworks models/button.STL
11.0 x 3.00 x 6.00

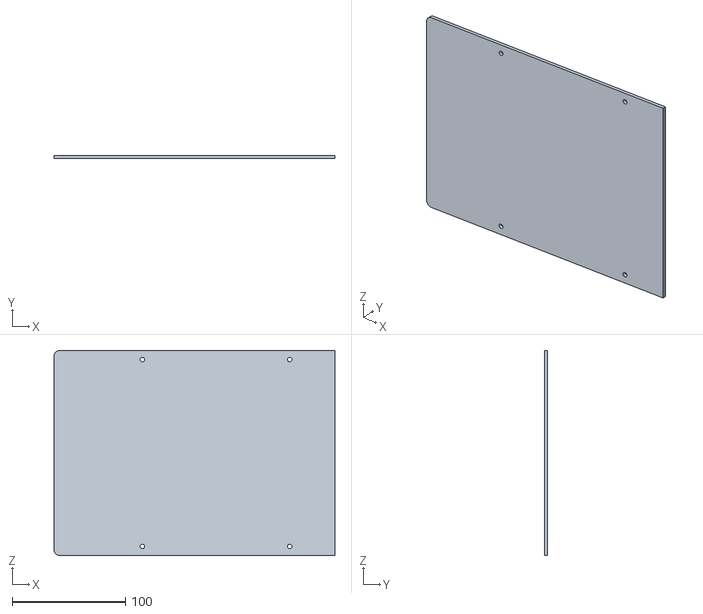
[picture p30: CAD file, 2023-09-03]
Solidoworks models/BasePlate.STL
248.0 x 3.00 x 181.0

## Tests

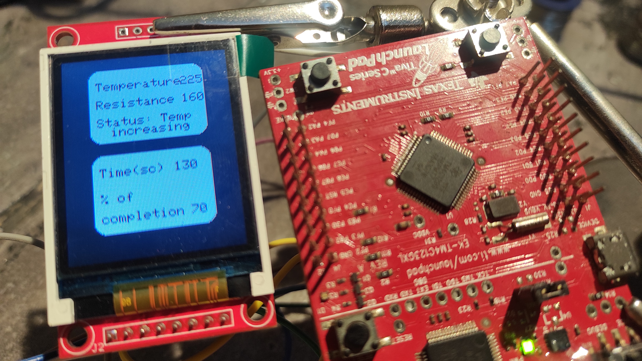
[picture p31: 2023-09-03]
TFT_Test.jpg

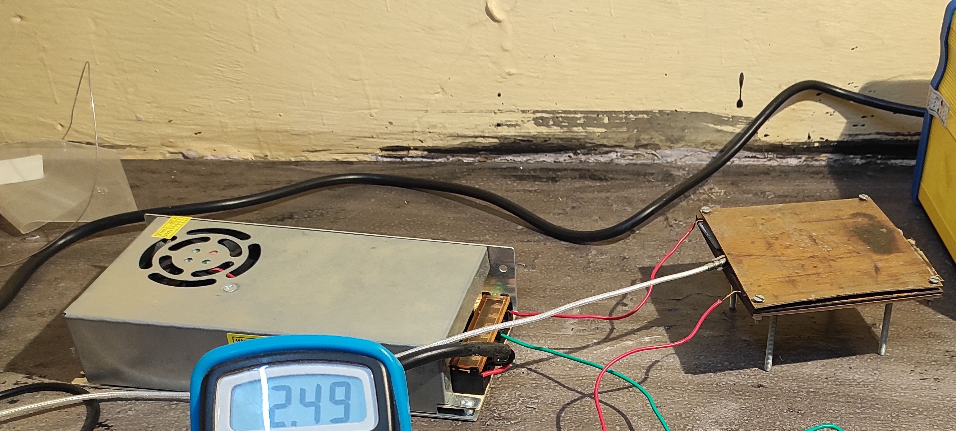
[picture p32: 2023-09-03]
Assembly_TestSetup.jpg

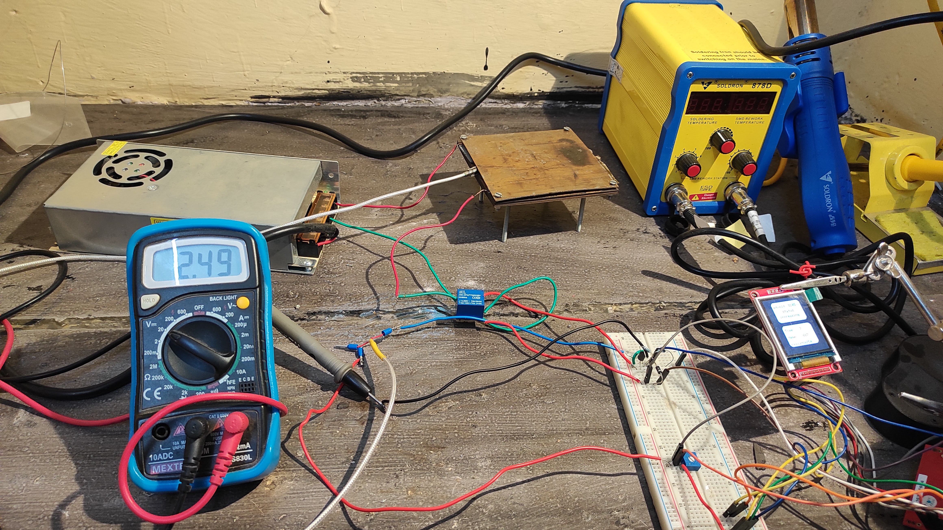
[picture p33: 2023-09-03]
Integrated_TestSetup.jpg

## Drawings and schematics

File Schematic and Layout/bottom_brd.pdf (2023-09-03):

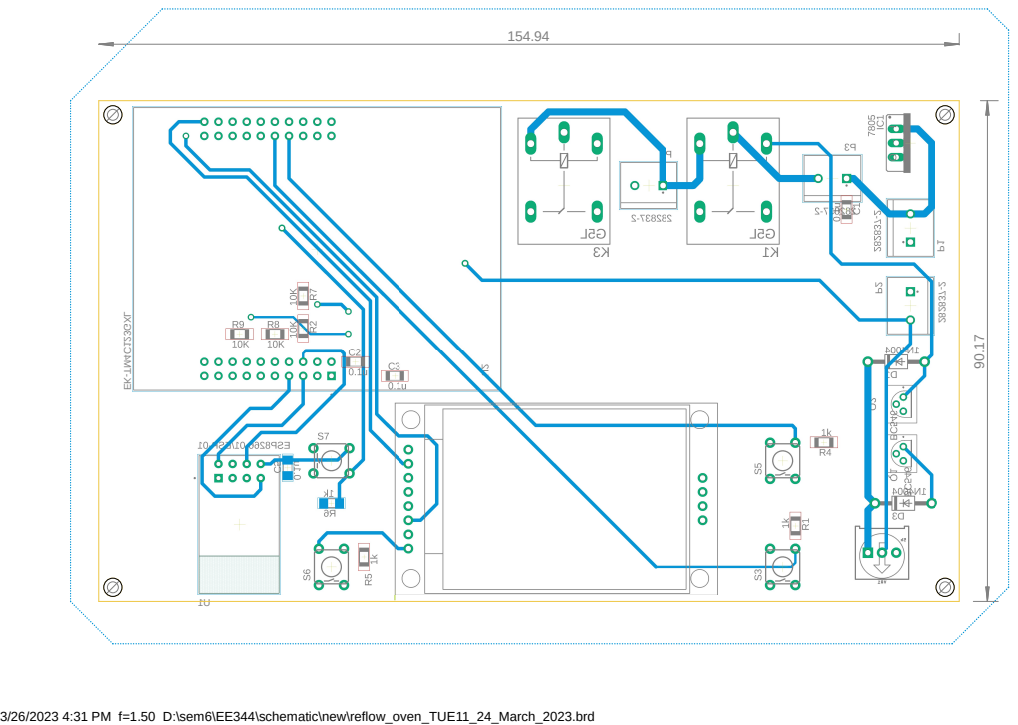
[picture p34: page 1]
3/26/2023 4:31 PM f=1.50 D:\sem6\EE344\schematic\new\reflow_oven_TUE11_24_March_2023.brd EK⁻TM⁴C¹²³GXL

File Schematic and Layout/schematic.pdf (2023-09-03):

## Temp. sen Push Buttons

## Power Block

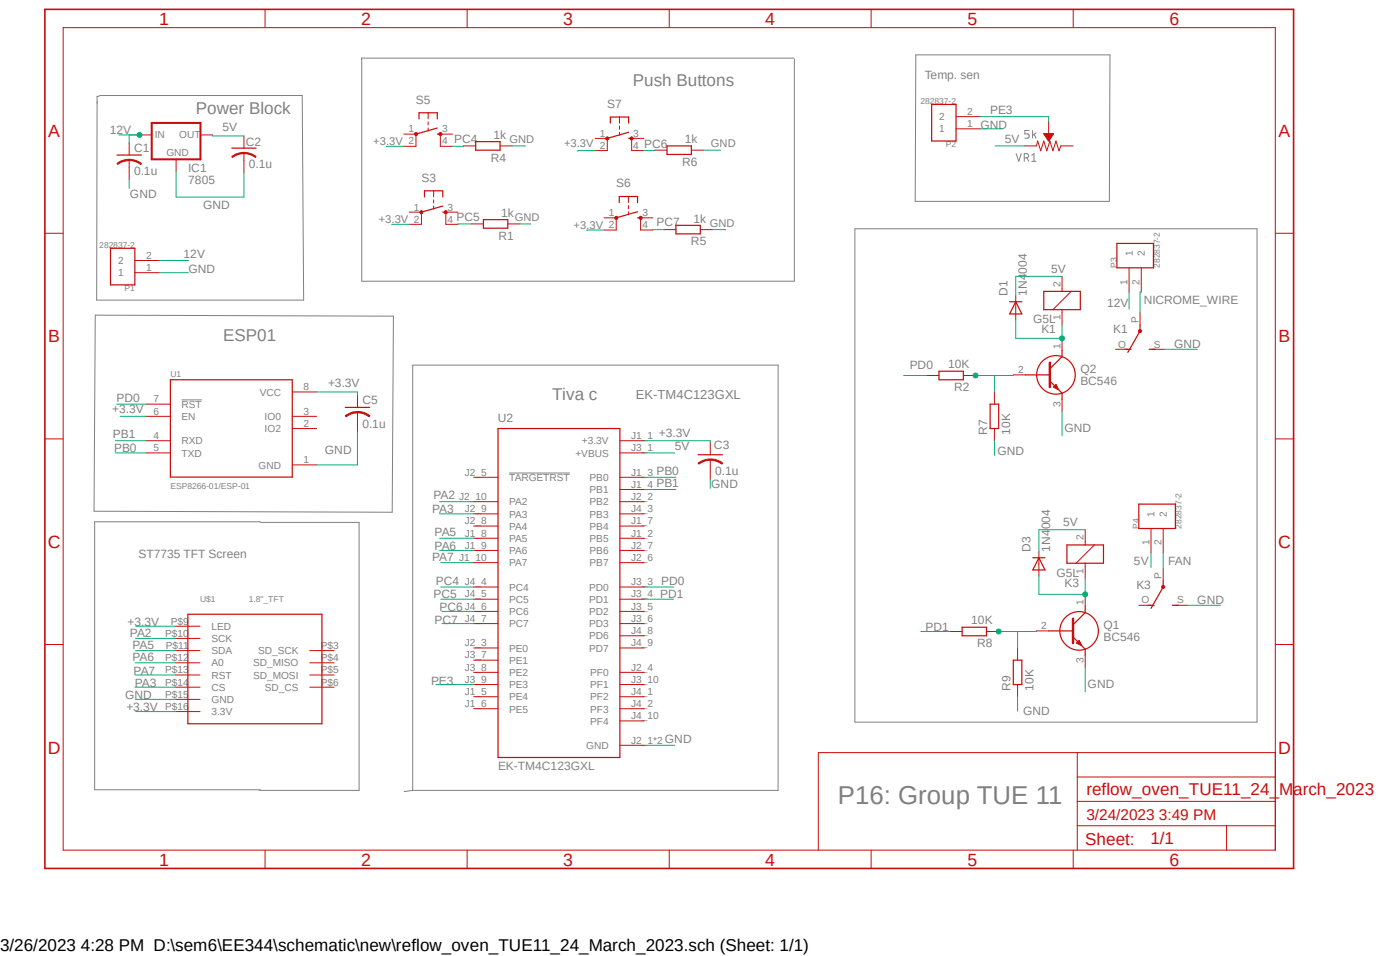
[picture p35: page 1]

P16: Group TUE 11

Sheet: 1/1

3/26/2023 4:28 PM D:\sem6\EE344\schematic\new\reflow_oven_TUE11_24_March_2023.sch (Sheet: 1/1)

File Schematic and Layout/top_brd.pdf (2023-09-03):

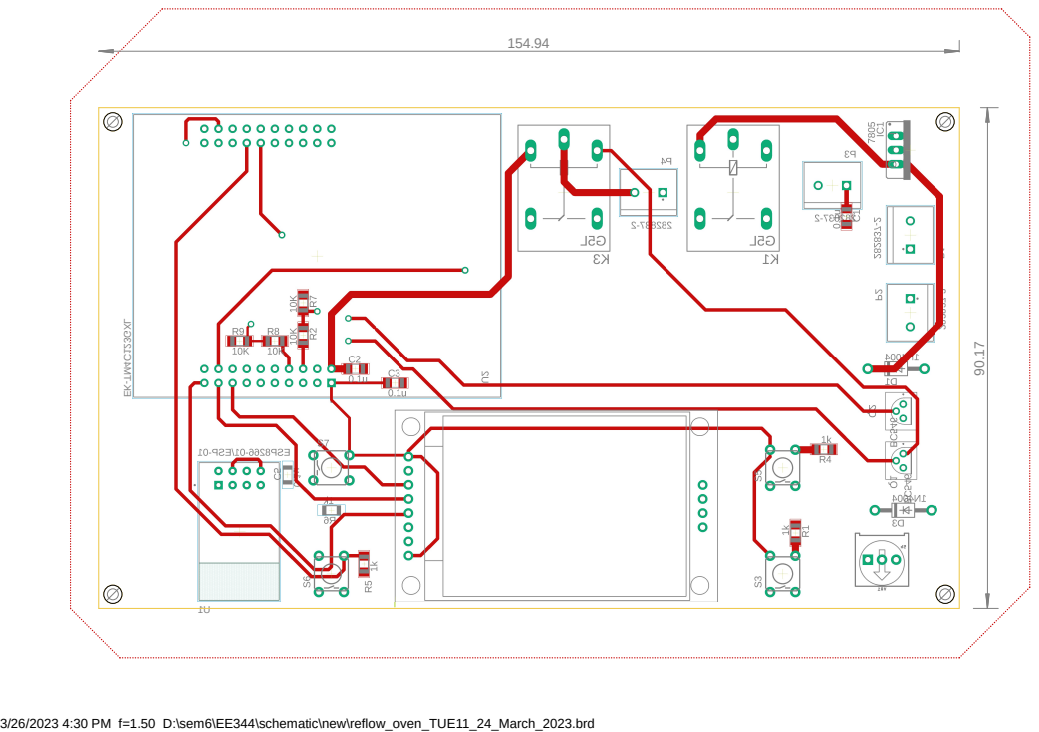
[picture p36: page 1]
3/26/2023 4:30 PM f=1.50 D:\sem6\EE344\schematic\new\reflow_oven_TUE11_24_March_2023.brd EK⁻TM⁴C¹²³GXL

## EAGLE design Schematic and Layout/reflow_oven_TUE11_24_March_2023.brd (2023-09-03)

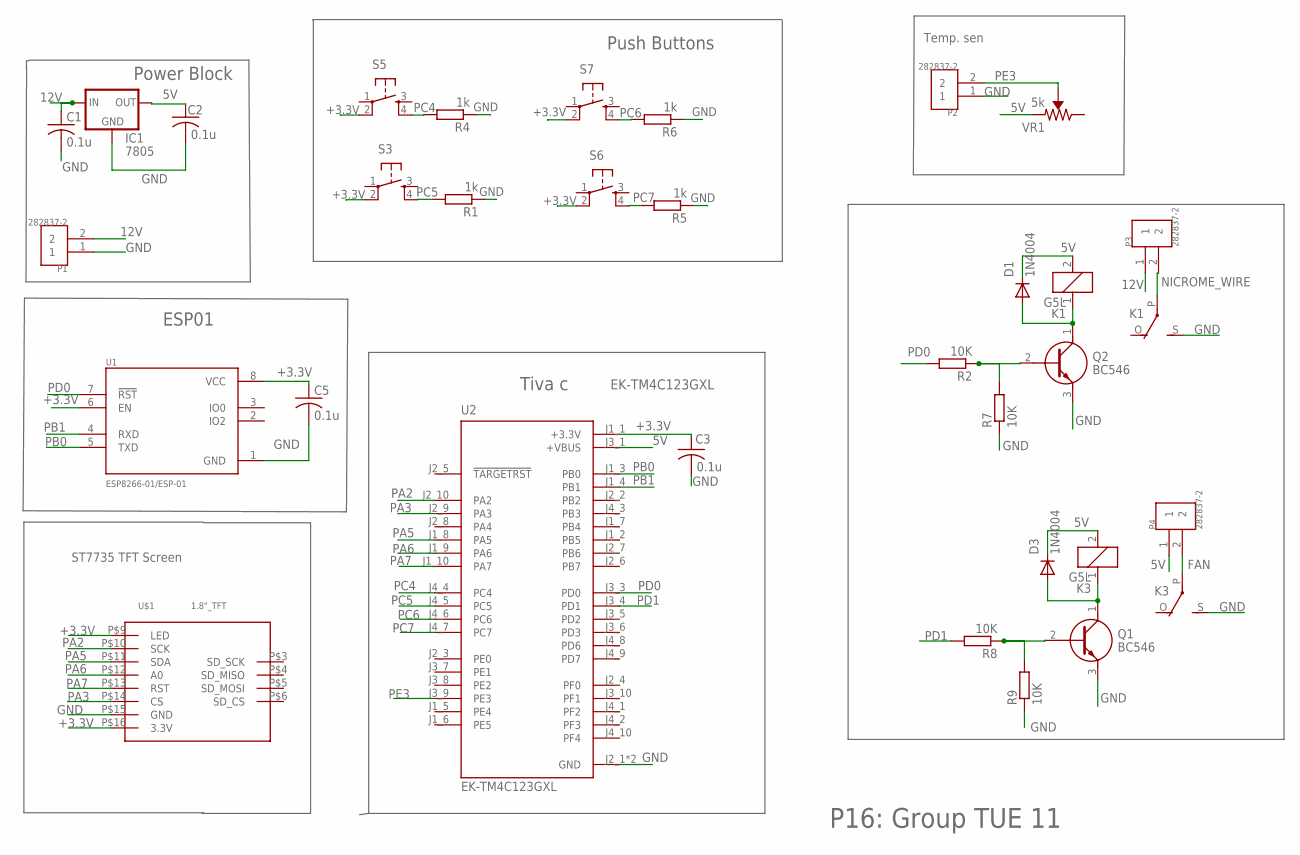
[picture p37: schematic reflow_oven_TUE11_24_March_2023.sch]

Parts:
C1, C2, C3, C5: 0.1u; C1206
D1, D3: 1N4004; DO41-10
IC1: 7805; 78XXS
K1, K3: G5L; G5LE
P1, P2, P3, P4: 282837-2; TE_282837-2
Q1, Q2: BC546
R1, R4, R5, R6: 1k; R1206
R2, R7, R8, R9: 10K; R1206
S3, S5, S6, S7: TAC_SWITCHPTH; TACTILE-PTH
U1: ESP8266-01/ESP-01; XCVR_ESP8266-01/ESP-01
U2: EK-TM4C123GXL; MODULE_EK-TM4C123GXL
U$1: 1.8"_TFT
VR1: 5k; TRIMPOT-PTH-3386U

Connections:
5V: C2.1, D1.C, D3.C, IC1.OUT, K1.2, K3.2, P4.1, U2.J3_1 (+VBUS), VR1.1 (CCW)
12V: C1.1, IC1.IN, P1.2, P3.1
+3.3V: C3.1, C5.1, S3.2, S5.2, S6.2, S7.2, U1.6 (EN), U1.8 (VCC), U2.J1_1 (+3.3V), U$1.P$9 (LED), U$1.P$16 (3.3V)
FAN: K3.P, P4.2
GND: C1.2, C2.2, C3.2, C5.2, IC1.GND, K1.S, K3.S, P1.1, P2.1, Q1.3 (E), Q2.3 (E), R1.1, R4.1, R5.1, R6.1, R7.1, R9.1, U1.1 (GND), U2.J2_1 (GND), U2.J3_2 (GND), U$1.P$15 (GND)
unnamed: Q2.2 (B), R2.1, R7.2
unnamed: D1.A, K1.1, Q2.1 (C)
unnamed: Q1.2 (B), R8.1, R9.2
unnamed: D3.A, K3.1, Q1.1 (C)
NICROME_WIRE: K1.P, P3.2
PA2: U2.J2_10 (PA2), U$1.P$10 (SCK)
PA3: U2.J2_9 (PA3), U$1.P$14 (CS)
PA5: U2.J1_8 (PA5), U$1.P$11 (SDA)
PA6: U2.J1_9 (PA6), U$1.P$12 (A0)
PA7: U2.J1_10 (PA7), U$1.P$13 (RST)
PB0: U1.5 (TXD), U2.J1_3 (PB0)
PB1: U1.4 (RXD), U2.J1_4 (PB1)
PC4: R4.2, S5.4, U2.J4_4 (PC4)
PC5: R1.2, S3.4, U2.J4_5 (PC5)
PC6: R6.2, S7.4, U2.J4_6 (PC6)
PC7: R5.2, S6.4, U2.J4_7 (PC7)
PD0: R2.2, U1.7 (!RST), U2.J3_3 (PD0)
PD1: R8.2, U2.J3_4 (PD1)
PE3: P2.2, U2.J3_9 (PE3), VR1.2 (WIPER)

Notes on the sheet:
Tiva c
ESP01
ST7735 TFT Screen
Temp. sen
Push Buttons
Power Block
P16: Group TUE 11
EK-TM4C123GXL

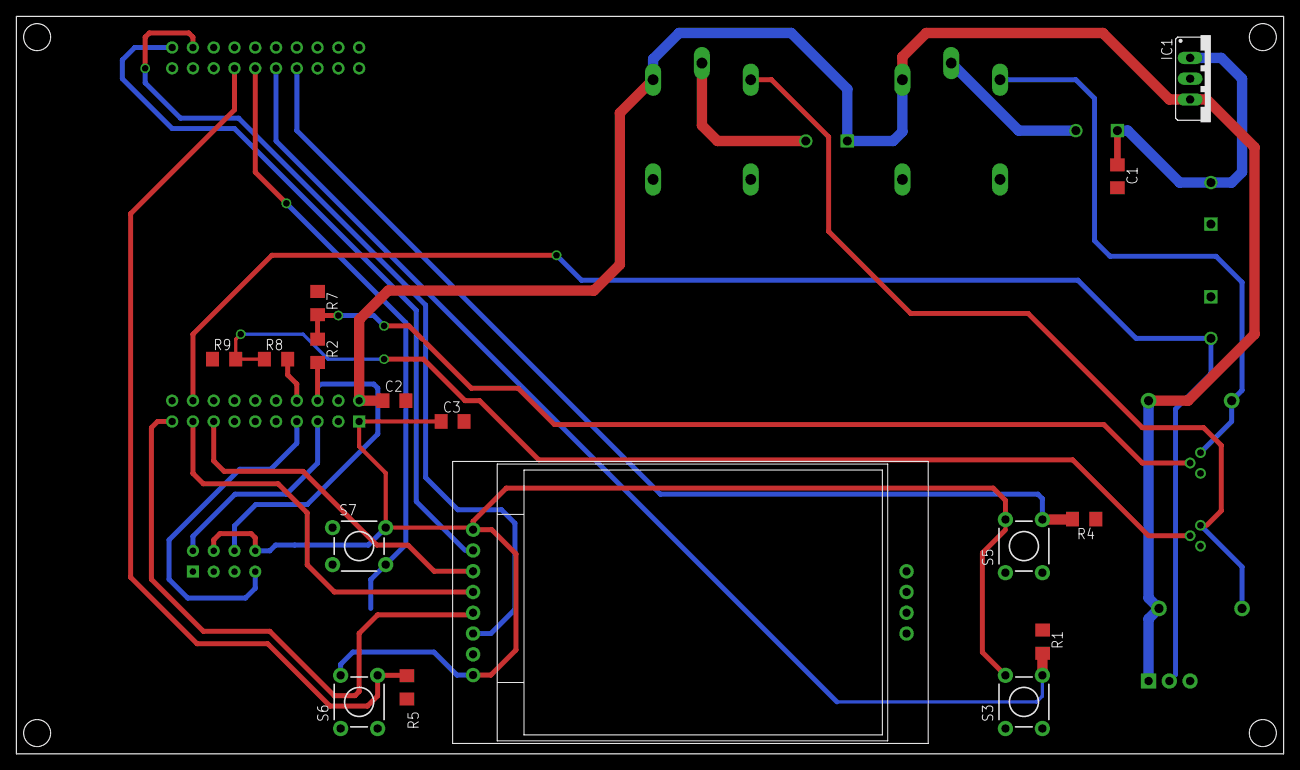
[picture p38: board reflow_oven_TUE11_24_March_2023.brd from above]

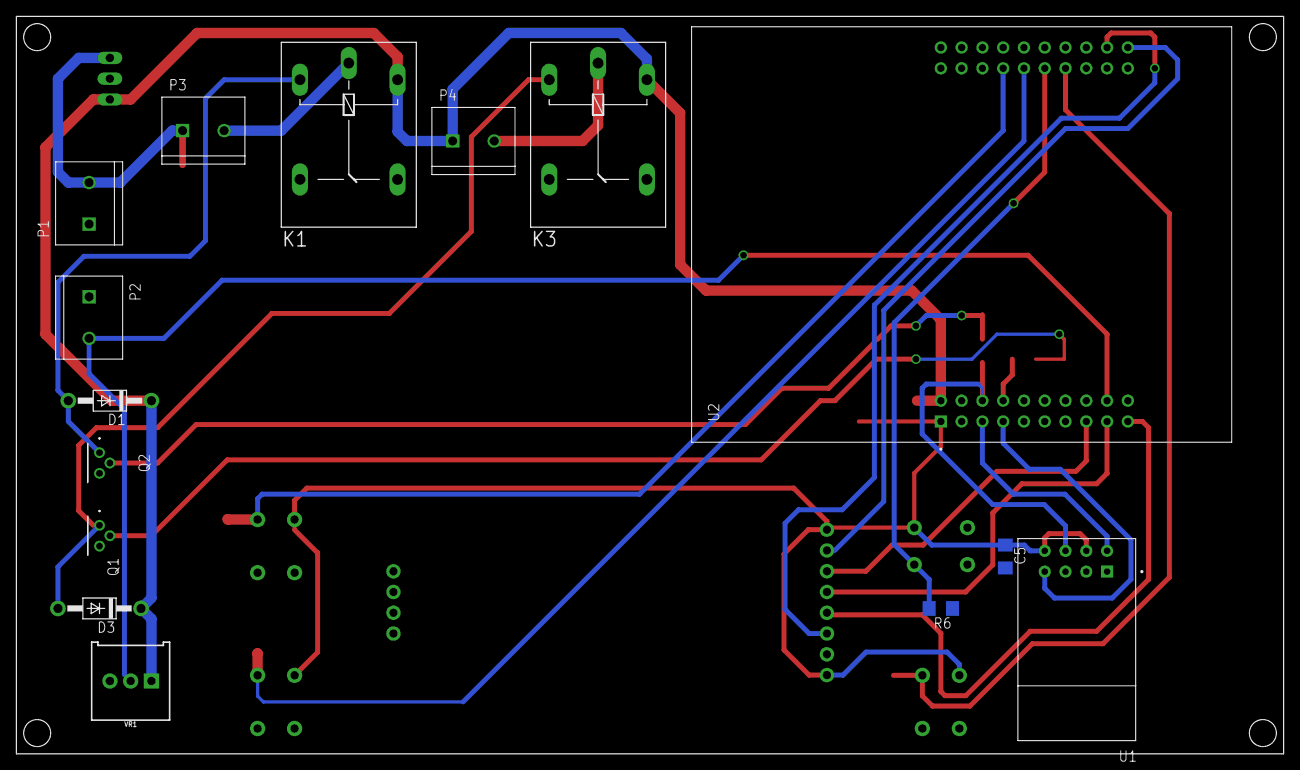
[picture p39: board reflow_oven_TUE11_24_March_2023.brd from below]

Board: 2 copper layers, 154.9 x 90.2 mm, 31 parts (15 on the bottom side), 24 nets.

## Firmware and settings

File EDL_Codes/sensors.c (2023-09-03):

#include "myLib.h"
//----------------------------------------
// Prototypes
//----------------------------------------

// TO STORE THE VALUE IN VARIABLE ADC0Value FOR EVERY SAMPLING
uint32_t ADC0Value[1];

//---------------------------------------------------------------------------
// hardware_init()
//---------------------------------------------------------------------------
void relay_init(){
    SysCtlPeripheralEnable(SYSCTL_PERIPH_GPIOD);
    GPIOPinTypeGPIOOutput(GPIO_PORTD_BASE, GPIO_PIN_0 | GPIO_PIN_1);
}

// (pin PD0)-> nichrome wire,
// (pin PD1)-> fan\
// 1 -> only nichrome wire on and fan is off
// 2 -> nichrome wire in on and fan both on
// 3 -> only fan is on, nichrome is off
void relay_on(int number){
    if(number == 1){
        GPIOPinWrite(GPIO_PORTD_BASE, GPIO_PIN_0|GPIO_PIN_1, 0x01);
    }else if(number == 2){
        GPIOPinWrite(GPIO_PORTD_BASE, GPIO_PIN_0|GPIO_PIN_1, 0x03);
    }else if(number == 3){
        GPIOPinWrite(GPIO_PORTD_BASE, GPIO_PIN_0|GPIO_PIN_1, 0x02);
    }
}

void adc_init(void)
{
    //Set CPU Clock to 40MHz. 400MHz PLL/2 = 200 DIV 5 = 40MHz
    //SysCtlClockSet(SYSCTL_SYSDIV_5|SYSCTL_USE_PLL|SYSCTL_XTAL_16MHZ|SYSCTL_OSC_MAIN);

    // ADD Tiva-C GPIO setup -
    SysCtlPeripheralEnable(SYSCTL_PERIPH_ADC0); // ENABLE ADC0 MODUL
    SysCtlPeripheralEnable(SYSCTL_PERIPH_GPIOE); // ENABLE GPIO for ADC0 MODULE

    GPIOPinTypeADC(PORT_E,GPIO_PIN_3);// ENABLE AN0 OF ADC0 MODULE
    // ADC0 MODULE, TRIGGER IS PROCESSOR EVENT, SEQUENCER 0 IS CONFIGURED
    ADCSequenceConfigure(ADC_0, 1, ADC_TRIGGER_PROCESSOR, 0);

    // ADC0 MODULE, SEQUENCER 0 , FOR 1 SAMPLING, INPUT IS FROM CHANNEL 0 PE3
    ADCSequenceStepConfigure(ADC_0, 1, 0, ADC_CTL_CH0);
    // ENABLE THE SEQUENCE 1 FOR ADC0
    ADCSequenceEnable(ADC_0, 1);
}

int ADC_conv(void)
{
    // CLEAR INTERRUPT FLAG FOR ADC0, SEQUENCER 1
    ADCIntClear(ADC_0, 1);
    // TRIGGER IS GIVEN FOR ADC 0 MODULE, SEQUENCER 1
    ADCProcessorTrigger(ADC_0, 1);
    // STORE THE CONVERTED VALUE FOR ALL DIFFERENT SAMPLING IN ARRAY
    //ui32ADC0Value
    ADCSequenceDataGet(ADC_0, 1, ADC0Value);
    return ADC0Value[0];
}

float volt_to_resistor(ptvolt){
    float res_side = 120;
    float v_pow = 3.3;
    float v_adc = ptvolt*v_pow/4096;
    float v_high = 5;
    float resistor = res_side*v_adc*(v_high-v_adc);
    return v_adc*100;
}

int resistor_to_temp(float resistor){
    // 163 high high very
    // 160 la band karo -> 250 degree
    // 112 room temperature 28 degree
    int high_temp = 250;
    int room_temp = 28;
    int res_high = 160;
    int res_normal = 112;
    int temp;
    temp = 28+(resistor-res_normal)*(high_temp-room_temp)/(res_high-res_normal);
    return temp;
}

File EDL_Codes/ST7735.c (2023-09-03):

/***************************************************
  This is a library for the Adafruit 1.8" SPI display.
This library works with the Adafruit 1.8" TFT Breakout w/SD card
  ----> http://www.adafruit.com/products/358
The 1.8" TFT shield
  ----> https://www.adafruit.com/product/802
The 1.44" TFT breakout
  ----> https://www.adafruit.com/product/2088
as well as Adafruit raw 1.8" TFT display
  ----> http://www.adafruit.com/products/618
  Check out the links above for our tutorials and wiring diagrams
  These displays use SPI to communicate, 4 or 5 pins are required to
  interface (RST is optional)
  Adafruit invests time and resources providing this open source code,
  please support Adafruit and open-source hardware by purchasing
  products from Adafruit!
  Written by Limor Fried/Ladyada for Adafruit Industries.
  MIT license, all text above must be included in any redistribution

  Ported to tm4c123gh6pm by Julian Fell.
 ****************************************************/
// 128x160 pixels, each character of 8x6 pixels.
#include "ST7735.h"
# include "myLib.h"
//*****************************************************************************
//
// Local Defines
//
//*****************************************************************************

#define SCREEN_WIDTH 128
#define SCREEN_HEIGHT 160

#define DELAY 0x80

#define RST  GPIO_PIN_7
#define DXL  GPIO_PIN_6
#define CSX  GPIO_PIN_3

#define SET_LOW(x) GPIOPinWrite(GPIO_PORTA_BASE, x, 0)
#define SET_HIGH(x) GPIOPinWrite(GPIO_PORTA_BASE, x, x)

#define swap(a, b) { int16_t t = a; a = b; b = t; }

//*****************************************************************************
//
// Private Variables
//
//*****************************************************************************

int8_t colstart, rowstart, rotation, textsize;
int16_t wrap,cursor_y,cursor_x;
uint16_t textcolour,textbgcolour;
uint32_t width, height;

//*****************************************************************************
//
// SPI command wrappers
//
//*****************************************************************************
void spiWrite(uint8_t c) 
{
  SET_LOW(CSX);
  SSIDataPut(SSI0_BASE, c);
  while ( SSIBusy(SSI0_BASE) ) {}
  SET_HIGH(CSX);
}

void writeCommand(uint8_t c) 
{
  SET_LOW(DXL);
  spiWrite(c);
}

void writeData(uint8_t c) 
{
  SET_HIGH(DXL);
  spiWrite(c);
} 


//*****************************************************************************
//
// Screen Initialisation
//
//*****************************************************************************
static const uint8_t
  initCommands[] = {                 // Init for 7735R, (green tab)
    8,                       // 8 commands in list:
    ST7735_SWRESET,   DELAY,  //  1: Software reset, 0 args, w/delay
      150,                    //     150 ms delay

    ST7735_SLPOUT ,   DELAY,  //  2: Out of sleep mode, 0 args, w/delay
      255,                    //     500 ms delay

    ST7735_COLMOD , 1      ,  // 15: set colour mode, 1 arg, no delay:
      0x05 ,                 //     16-bit colour

    ST7735_MADCTL  ,  DELAY,  
      255,                    //     500 ms delay

    ST7735_MADCTL , 1      ,  
      0xc8 ,                 
    ST7735_GMCTRP1, 16      , //  1: Magical unicorn dust, 16 args, no delay:
      0x02, 0x1c, 0x07, 0x12,
      0x37, 0x32, 0x29, 0x2d,
      0x29, 0x25, 0x2B, 0x39,
      0x00, 0x01, 0x03, 0x10,
    ST7735_GMCTRN1, 16      , //  2: Sparkles and rainbows, 16 args, no delay:
      0x03, 0x1d, 0x07, 0x06,
      0x2E, 0x2C, 0x29, 0x2D,
      0x2E, 0x2E, 0x37, 0x3F,
      0x00, 0x00, 0x02, 0x10,
    ST7735_DISPON ,    DELAY, //  4: Main screen turn on, no args w/delay
      100 };                  //     100 ms delay

// Companion code to the above table.  Reads and issues
// a series of LCD commands stored in byte array.
void commandList(const uint8_t *addr) 
{
  uint8_t  numCommands, numArgs;
  uint16_t ms;

  numCommands = *(addr++);   // Number of commands to follow
  while(numCommands--) {                // For each command...
    writeCommand(*(addr++)); //   Read, issue command
    numArgs  = *(addr++);    //   Number of args to follow
    ms       = numArgs & DELAY;          //   If hibit set, delay follows args
    numArgs &= ~DELAY;                   //   Mask out delay bit
    while(numArgs--) {                   //   For each argument...
      writeData(*(addr++));  //     Read, issue argument
    }

    if(ms) {
      ms = *(addr++); // Read post-command delay time (ms)
      if (ms == 255) {
        ms = 500;     // If 255, delay for 500 ms
      } 
      delay_ms(ms/15);
    }

  }
}

void LcdInit(void) 
{
  /* Setup Tiva hardware for SPI communication */
  SysCtlPeripheralEnable(SYSCTL_PERIPH_SSI0);
  SysCtlPeripheralEnable(SYSCTL_PERIPH_GPIOA);

  /* Set DXL, RST and CSX Pins as outputs for manual toggling */
  GPIOPinTypeGPIOOutput(GPIO_PORTA_BASE, DXL | RST | CSX);

  /* Configure the pin muxing, Repurpose them for SSI use */
  GPIOPinConfigure(GPIO_PA2_SSI0CLK);
  GPIOPinConfigure(GPIO_PA4_SSI0RX);
  GPIOPinConfigure(GPIO_PA5_SSI0TX);

  /* Configure the pins for use by the SSI */
  GPIOPinTypeSSI(GPIO_PORTA_BASE, GPIO_PIN_2 | GPIO_PIN_4 | GPIO_PIN_5);

  /* Set the SSI Interface */
  SSIConfigSetExpClk(SSI0_BASE, SysCtlClockGet(), SSI_FRF_MOTO_MODE_0,
                     SSI_MODE_MASTER, SysCtlClockGet()/10, 8);

  /* Enable the SSI0 module */
  SSIEnable(SSI0_BASE);

  /* Toggle reset */
  SET_HIGH(RST);
  delay_ms(40);
  SET_LOW(RST);
  delay_ms(40);
  SET_HIGH(RST);
  delay_ms(40);

  /* Initialise default values */
  colstart = 0;
  rowstart = 0;
  width = SCREEN_WIDTH;
  height = SCREEN_HEIGHT;
  wrap = 1;
  cursor_y = 0;
  cursor_x = 0;
  textsize = 1;
  textcolour = 0xFFFF;
  textbgcolour = 0xFFFF;

  /* Initialise LCD screen */
  commandList(initCommands);
}

//*****************************************************************************
//
// Basic Drawing Functions
//
//*****************************************************************************

uint16_t swapColour(uint16_t x) 
{ 
  return (x << 11) | (x & 0x07E0) | (x >> 11);
}

void setAddrWindow(uint8_t x0, uint8_t y0, uint8_t x1, uint8_t y1) 
{
  writeCommand(ST7735_CASET); 
  writeData(0x00);
  writeData(x0+colstart);   
  writeData(0x00);
  writeData(x1+colstart);  

  writeCommand(ST7735_RASET); 
  writeData(0x00);
  writeData(y0+rowstart);  
  writeData(0x00);
  writeData(y1+rowstart); 

  writeCommand(ST7735_RAMWR);
}

void pushColour(uint16_t colour) 
{
  SET_HIGH(DXL);
  spiWrite(colour >> 8);
  spiWrite(colour);
}

void drawPixel(int16_t x, int16_t y, uint16_t colour) 
{
  if((x < 0) ||(x >= width) || (y < 0) || (y >= height)) return;

  setAddrWindow(x,y,x+1,y+1);
  pushColour(colour);
}
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

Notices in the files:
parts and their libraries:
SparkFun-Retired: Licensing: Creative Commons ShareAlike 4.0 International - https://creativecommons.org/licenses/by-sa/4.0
